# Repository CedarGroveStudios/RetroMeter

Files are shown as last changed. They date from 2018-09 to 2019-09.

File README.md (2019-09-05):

# RetroMeter
A breakout and FeatherWing PCB family with CircuitPython code that converts a +/-10V CV signal to a current level compatible with a retro analog ammeter. USB or 3 to 6V battery powered (no internal battery charger). From the collaborative project with John Park’s Workshop.

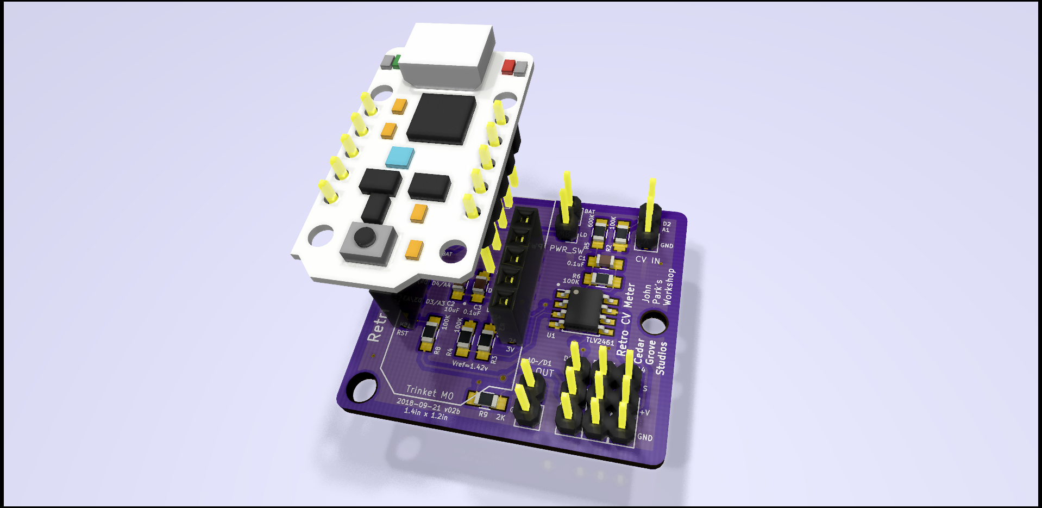
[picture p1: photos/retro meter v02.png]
Retro CV Meter and Trinket M0 Rendering


The Retro CV Meter breakout and FeatherWing board accepts a -10 to +10 volt signal and through an analog op-amp, translates it into a +3.3 to 0 volt signal connected to the Adafruit Trinket M0 or Feather's A1 analog input pin. The A0~ DAC output pin provides current output through a 2K-ohm resistor to the analog meter connection. The maximum DAC value (65535) produces 1.5mA to the attached meter.

The CircuitPython code reads the input voltage and adjusts the DAC output for the scale for the meter. The ``inertia_move`` helper integrates the incoming signal then sends the scaled and smoothed voltage to the on-board meter resistor to convert the voltage to current compabile with the analog meter. The integration routine protects the meter movement from sudden voltage changes.

The most recent version of the code reads a meter scale input from a potentiometer attached to pin A2. The D3 pin provides a PWM output proportional to the absolute value of the input voltage within the specified range.

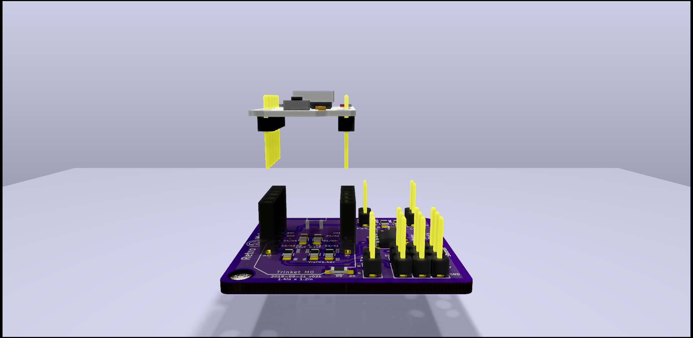
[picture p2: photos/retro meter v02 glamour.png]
Retro CV Meter and Trinket M0 Glamour Rendering


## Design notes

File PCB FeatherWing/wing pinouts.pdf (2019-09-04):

-EN | connect to GND to disable power also disables Feather MCU power
LED | glows when power is enabled
3V | 3.3 volt power from Feather MCU
GND | ground connection to/from Feather MCU

D5 | Digital output to LED buffer
D6 | Digital output to LED buffer
D9 | Digital output to LED buffer
A0 | DAC output to meter via R8 or R12
A2 | Analog input from input signal processing stage
A3 | Analog input from range selection potentiometer

D10 digital output to piezo speaker

LEDs:

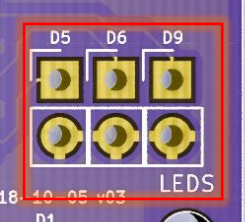
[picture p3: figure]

High-current buffered outputs for LEDs; 25mA max (connect anode to upper pin, cathode to lower pin) Recommended that LED current and brightness be controlled by PWM instead of adjusting R9-R11 values.

RANGE_SEL:
Range selection potentiometer connection (potentiometer wiper attached to S pin)

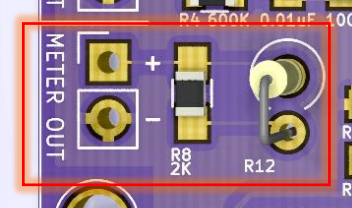
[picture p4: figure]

METER OUT:
Analog output to meter (note polarity)

R8 and R12:
Series resistance matched to meter full-scale current at +3.3volts

CV INPUT:
-10 volt to +10 volt control voltage input to signal processing stage

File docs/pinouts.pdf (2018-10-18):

PWR_SW:
Power switch pins in series with the positive battery input terminal

M OUT:
Analog output to meter (M = +, G = -)

R9:
Series resistance matched to meter full-scale current at +3.3volts

SenseBit Inputs/Outputs:
Unbuffered GPIO directly connected to the Trinket M0
(connect input/output signal to upper pin;
+3.3 volts power and ground available on the remaining two pins)

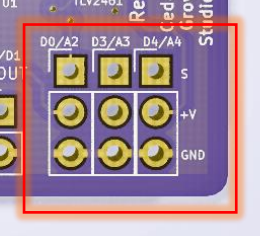
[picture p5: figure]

CV INPUT:
-10 volt to +10 volt control voltage input to signal processing stage

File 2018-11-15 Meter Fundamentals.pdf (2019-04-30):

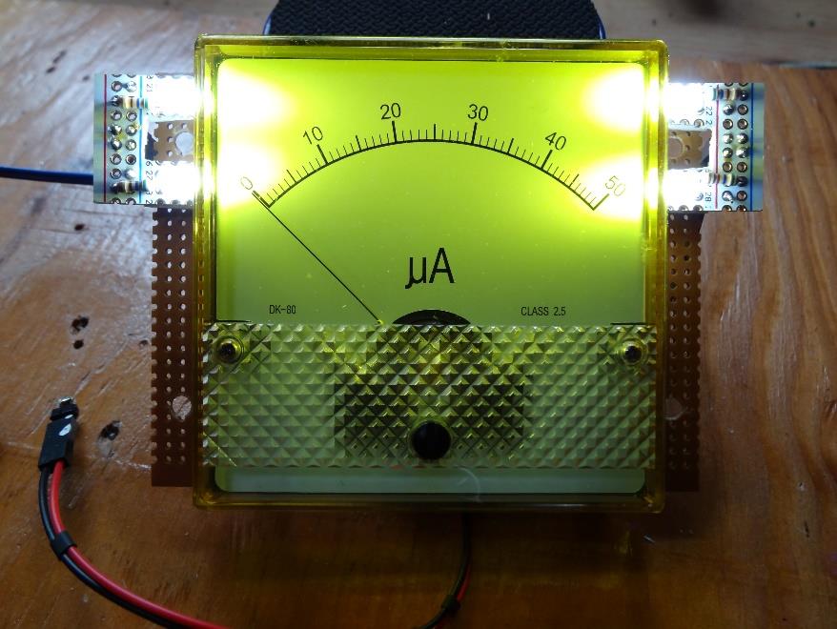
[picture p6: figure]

Meter Fundamentals.docx | 1

# Analog Meter Fundamentals

Jan Goolsbey, Cedar Grove Studios
November 2018

## 1. Analog Meter Fundamentals

Analog meters have a wonderful retro look and are easy to read with a glance. Can you make one work with your project? With one of these meters, you’ll be able to display either voltage or current of almost any range or value with some simple components. Ohm’s Law will become your analog friend.

### 1.1 Overview

Analog meters used to be an excellent and sometimes the
only way to display electronic circuit activity. They are round,
square, rectangular, lighted, mirrored, small and large, slow and fast. They have been used to measure voltage, current, power, resistance, radio frequency (RF) fields, engine RPMs, audio volume units (VU), and just about anything else. The meter’s lightweight needle darts above a printed scale,
eventually settling to point at the measured value.

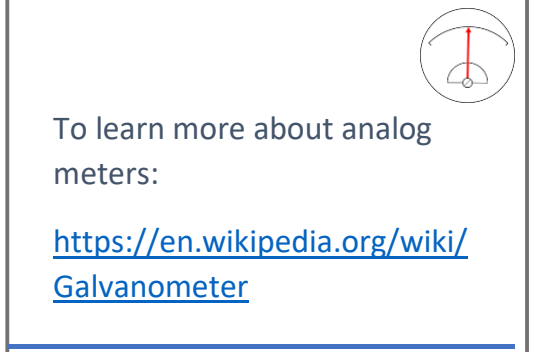
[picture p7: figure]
To learn more about analog meters:; https://en.wikipedia.org/wiki/ Galvanometer

Analog meters are closely related to galvanometers and motors. Common analog meters are built with magnets, a small coil of wire, jewel pivot bearings, fragile pointers, and a miniature spring (like the balance wheel hairspring in a mechanical timepiece), all sealed in a wind-tight case with a clear cover. With the proper components attached, these meters can measure signal levels as sensitive as millivolts and microamperes all the way to kilovolts and tens of
Amperes. Changing the displayed scale is as easy as printing
and attaching a new scale legend.

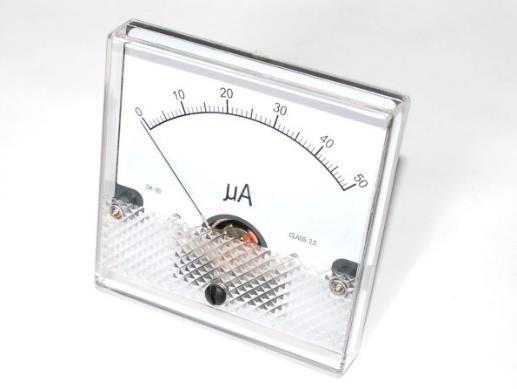
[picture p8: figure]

Although not widely in use as of this writing, analog meters are still available to purchase. Many meters can be reclaimed from old equipment and repurposed. An analog meter can add retro elegance to a modern project. Would one work with yours?

For the examples in this guide, we’ll be using a 50-
microampere analog panel meter from Adafruit (PID # 252). (https://www.adafruit.com/product/252)

### 1.2 Meter Electromechanics

Common analog meters consist of a moving wire coil suspended in a magnetic field created by a stationary core and surrounding permanent magnets. The coil is suspended on jeweled bearings with tension provided by one or two spiral wound springs that return the coil to a resting position when no current is applied. As current is applied to the coil, it deflects the attached indicator needle linearly in proportion to the amount of current flowing through the coil.

When no current is flowing through the meter, the indicator needle will rest at the zero point, usually on the left of the scale, sometimes in the center. If connected correctly, the needle will deflect towards the full-scale position in proportion to the current flowing through the meter. If the connection is reversed, the needle will move to a value less than the resting (zero) position. Reverse deflection below the limit of the scale can damage the sensitive and fragile coil assembly and should be avoided. Similarly, if too much current is applied, the coil will move beyond the full-scale value and cause similar damage to the

Adafruit’s Analog Panel Meter coil assembly. The slang phrase for pushing a meter beyond its physical limits until the needle hits a mechanical stop is called “pegging the meter.”

Moving-coil meters respond to direct-current (DC) flow. Most commercially available meters respond to current levels as low as 25 microamperes and up to 10 milliamperes full-scale. With some simple external components and Ohm’s Law, analog meters can be employed to display kilovolts and deca-amperes.

Using a meter for displaying a current level is simple: connect it in series between a power source and a load then read the value on the scale. The meter’s needle will point to a value as accurate as the meter can measure in its range, usually within 1% to 5% of the full-scale value. A resistor added across the meter’s terminals can be used to extend the current measurement range of the meter.

If it’s voltage that you want to measure with the analog meter, select and place a resistor in series with one of the meter’s terminals. The voltage range can be adjusted to a wide range by modifying the value of the series resistor.

We’ll need to know a couple of things about the meter to proceed, its full-scale current value (likely printed on the meter or accompanying documentation) and the voltage drop measured across the meter when the needle is deflected to full-scale. If you don’t know your meter’s full-scale current value or voltage drop, then briefly skip to section 3. Characterize the Meter to discover those values. You will need both in order to adapt the meter to measure a variety of full-scale voltage and current levels.

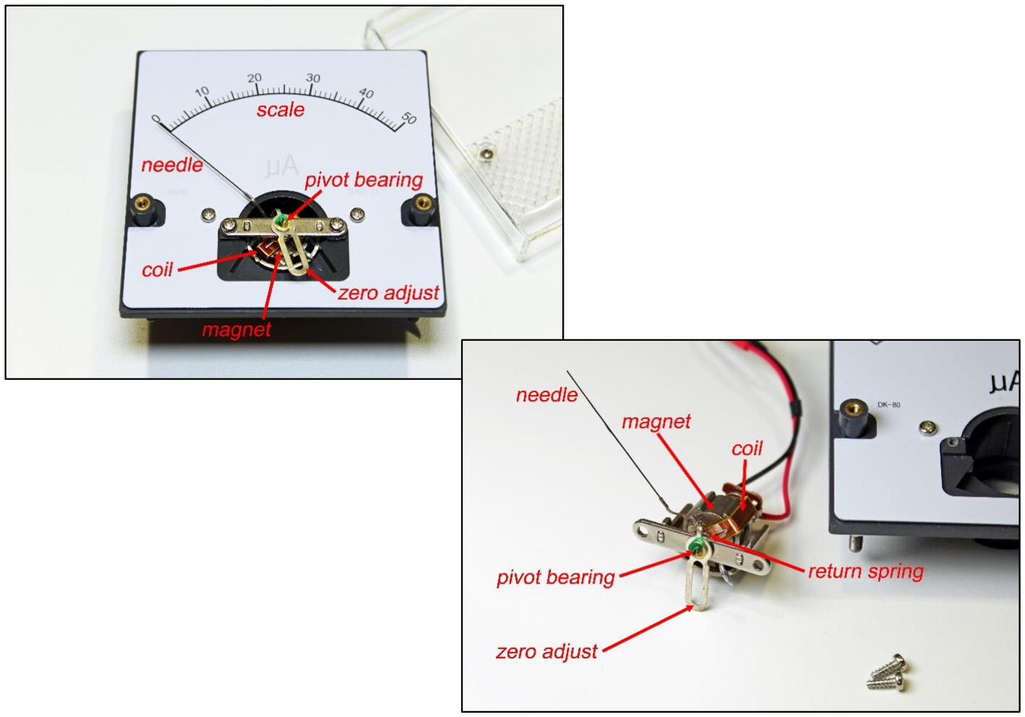
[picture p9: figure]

### 1.3 Measure Current

Measuring current is natural for most moving-coil analog meters. The meter’s primary mode of operation is to measure the amount of current passing
through its coil. To use a meter to measure the current flow of a circuit, select a meter with a full-scale value that is greater than the maximum current expected. Place the meter in series with the
power source and the circuit
under test (the “load”) to

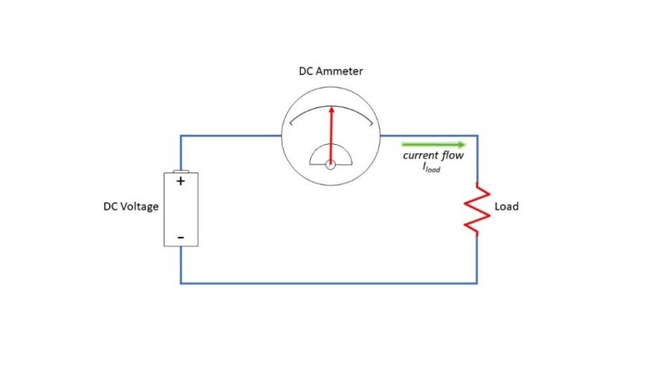
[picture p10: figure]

measure the amount of current the circuit is drawing from the power source.

Most meters are very sensitive and can only measure a small amount of current at full-scale. For example, our 50-microampere (uA) meter is too sensitive to measure the current through a typical light-emitting-diode (LED) since an LED will draw 5 to 20 milliamperes (mA). That’s at least 100 times the current the meter can handle and will certainly damage the meter! (Remember what happens when the needle goes past full-scale?) If you’re planning to measure higher values of current than the meter’s rated range, we’ll need to make a couple of calculations using Ohm’s Law.

1.3.1 More Current (Introducing the Shunt Resistor)
A resistor placed in parallel with the meter can be used to pass most of the circuit’s current around the meter while still allowing a smaller amount of current -- proportional to the total current – to pass through the meter. In effect, the parallel resistor shunts current that could damage the meter directly into the load. Here’s how it works.

The entire current to the load
passes through both the meter
and the shunt resistor. Because of differences between the meter’s internal resistance (Rmeter) and that of the shunt resistor (Rshunt), the meter will see a just fraction of the total current. That fraction is directly proportional to the ratio of the
meter and shunt resistance
values. If the load requires 50mA

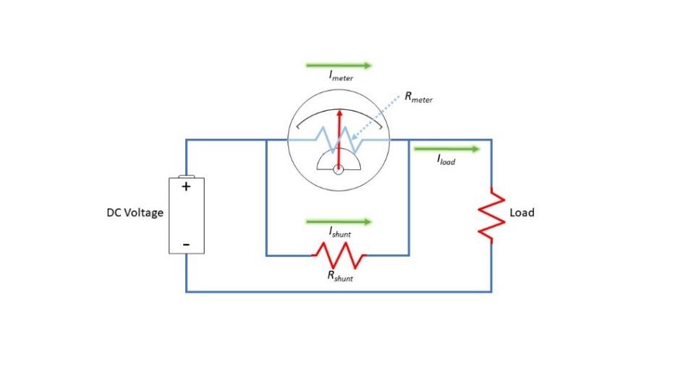
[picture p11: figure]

and if the meter can only indicate a maximum of 50uA (0.05mA), the shunt resistor will need to divert 49.95mA away from the meter.

Since the voltage across the shunt resistor is the same as the meter voltage, it’s easy to calculate the value of the shunt resistor. Here’s the formula:

Rsℎunt =

Vmeter

Iload − Imeter

=

Vmeter

Isℎunt

Substitute these values and solve:

Rsℎunt =

0.0922V
0.050A − 0.00005A = 1.85 oℎms

To bypass the current not used by the meter, our shunt resistor will need to have a value of 1.85 ohms.

We’ll need one more calculation to determine how much heat the shunt resistor will need to dissipate when the circuit draws the maximum of 50mA. For many electronic devices, heat dissipation is measured in Watts. Resistors with a higher wattage value can safely dissipate more heat than those of a low wattage. Shunt resistor heat dissipation is a very important number to know when measuring current; if exceeded, damage may occur.

The formula for determining wattage is:

Wsℎunt = Vmeter ∗ Isℎunt

Wsℎunt = 0.0922V ∗ 0.04995A = 0.0046W

Substituting the voltage across the shunt resistor (0.0922V) and its current (0.04995A) tells us that the shunt resistor will need to be sized to dissipate 4.6mW, well below a typical resistor’s 128mW (1/8W) maximum dissipation value.

DigiKey stocks a 1.82-ohm resistor with a resistance value close enough to work in this example given the +/-3% accuracy of the 50uA meter. This resistor’s specified 250mW dissipation value is more than adequate, as well.

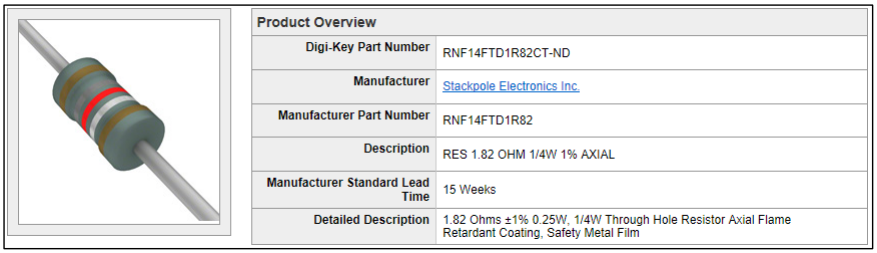
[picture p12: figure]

In summary, measuring current greater than the meter’s full-scale value is just a simple matter of understanding the maximum load current to be measured, the meter’s full-scale current value, and the

Vmeter = 92.2mV = 0.0922V

Iload = 50mA = 0.050A

Imeter = 50uA = 0.00005A meter voltage when the needle is at full-scale. Throw Ohm’s Law and a power formula into the mix and you can adjust the meter to measure almost any DC current value.

The printed scale may not match the new full-scale value. If that’s the case, look at the section, 2. Print a New Scale.

Now that we can measure various current values using an analog meter, it’s time to move on to measuring voltage.

### 1.4 Measure Voltage

A sensitive analog ammeter is capable of measuring voltage with the addition of a single series resistor. The resistor is used to limit the current traveling to the meter so that the meter can proportionally respond to the measured voltage
value.

In this diagram, we’re measuring
the voltage across a load that’s supplied by a battery. The battery’s DC voltage provides a current through the series resistor (Rseries) and the meter that is in proportion to the resistance of Rseries. For example,
let’s assume that we’re using our
friendly Adafruit 50uA meter and

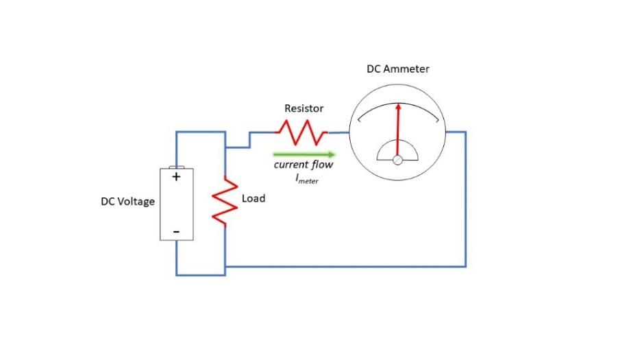
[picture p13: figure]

the battery is supposed to provide at least 12 volts. Let’s calculate the value of Rseries that will result in full-scale needle deflection if the voltage reaches 50 volts.

Rseries =

Vfullscale − Vmeter

Imeter

Substitute these values and solve:

Rseries =

50V − 0.0922V
0.000050A

= 998.16K oℎms

The closest value in DigiKey’s stock is 1M ohms. That value will introduce an error of only 0.2%, well within the meter’s accuracy.

Vfullscale = 50V

Imeter = 50uA = 0.000050A

Vmeter = 92.2mV = 0.0922V

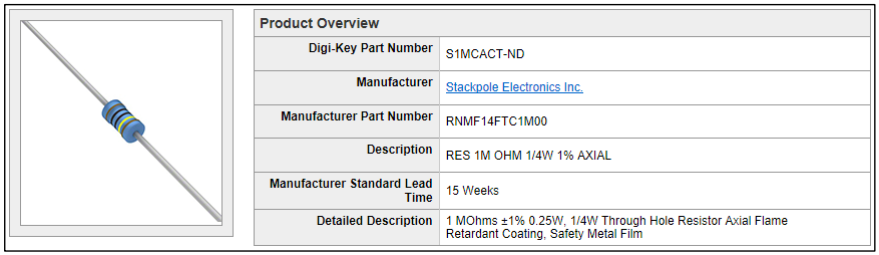
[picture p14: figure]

Let’s try one more example. We would like the full-scale voltage value to be 3.3 volts, the maximum voltage used by many microcontrollers.

Rseries =

Vfullscale − Vmeter

Imeter

Rseries =

3.3V − 0.0922V
0.000050A

= 64,156 oℎms

We’ll select a resistor as close to that as possible. DigiKey stocks resistors with values of 63.4K and 64.9K ohms. We’ll pick the closest one, 64.9K ohms. The error introduced by the resistor selection is just 1.2%, sufficient for most projects.

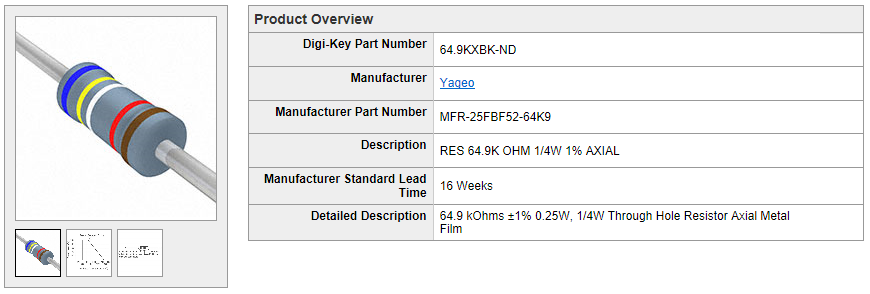
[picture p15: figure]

Okay, but the meter’s scale is shown as 0 to 50uA. The printed scale does not match the new full-scale value of 3.3 volts. The next section, 2. Print a New Scale, will help with that.

## 2. Print a New Scale

So, the 0 to 50 uA meter scale doesn’t represent the values you plan to measure? A new label can be made from a sheet of paper and a protractor. It can be drawn by hand or using your favorite software drawing, CAD, or photo tool. The process is pretty much the same regardless of the media or tool.

Most analog meter scales can be matched to a degree spread on a protractor. In the case of the Adafruit 50uA meter, the needle travels along 90 degrees of a circular arc with a radius of 4cm. Laying that out using a protractor or on an image of a protractor is the first step. After that, you can add the graduations and the legend as required. If the scale you need is linear, that’s easy. A logarithmic scale will probably take longer and will require some planning and patience. If you’re making a weather gauge, then you may only need three colorful symbols (stickers?) for sunny, cloudy, and precipitation such as an image of the warm sun, a menacing cloud, and when it’s raining cats and dogs. Use your imagination!

Once designed, print a draft version to make certain it will fit. For most meters, cut the paper scale to a rectangle the size of the visible window. After removing the meter’s clear cover, place the new scale over the old scale and under the needle. Try not to bump the needle or meter movement – it’s easy to throw the sensitive parts out of alignment. If the draft scale fits correctly, print the final scale on photographic paper, otherwise continue to work the dimensions until the draft scale fits. Secure the new scale with two or three dots of glue from a glue stick or use three pieces of clear tape along the top and sides. If you use tape, keep the overlap on the face of the scale as small as possible so the tape won’t be visible.

Free-use protractor images and design files can be found on many Internet sites. One of my favorites is Michael Ossmann’s excellent quality Print a Protractor site (http://www.ossmann.com/protractor/). The files are available for use under a Creative Commons Attribution 2.5 License.

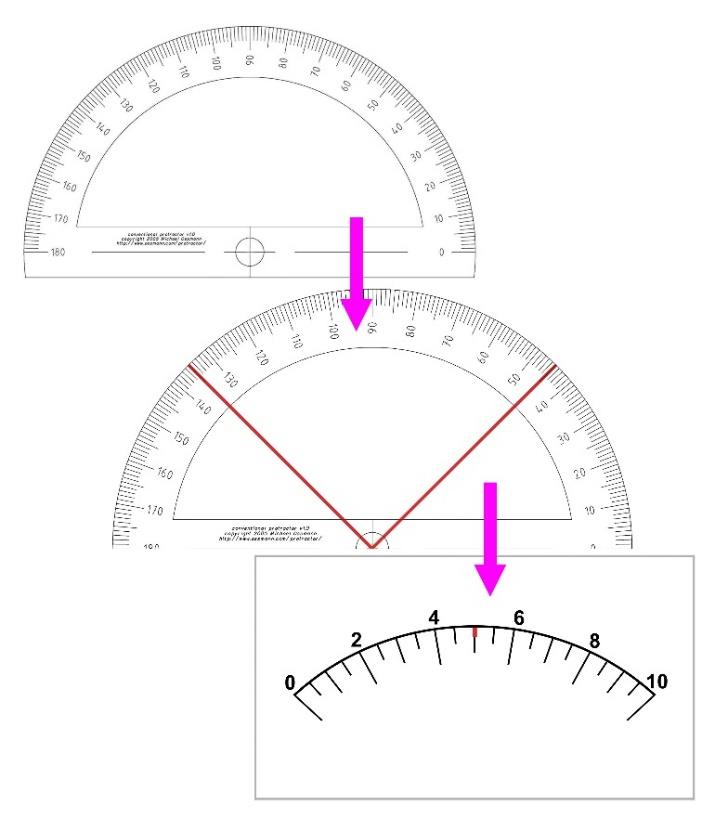
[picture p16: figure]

## 3. Characterize the Meter

### 3.1 Find the Meter’s Numbers

If you are repurposing a used meter, it’s likely that the full-scale current range isn’t known. We’ll walk through the process to determine a meter’s range using a stable power source, a few resistors, two potentiometers, and a digital volt meter – providing that the meter movement wasn’t previously damaged, of course.

First, carefully open the case of the meter to confirm that the meter is indeed a moving coil meter (capable of responding to DC current). If you see a fixed coil, it may respond only to voltage or AC current and won’t be useful for anything else than that.

Next, look to see if resistors, copper bars, or other components are attached to the wires coming from the meter coil. If so, carefully remove the components and connect the coil wires to the meter terminals, being extra careful not to disturb the meter movement or needle. Close the meter case when finished removing components. The meter should now respond to a DC current input.

Since most meters will have a manufacturer’s name and model number, search the Internet for information about the meter. The range of the meter and voltage drop may be easy to find from a reliable source like the manufacturer or a commercial supplier. If so, you’re done and can skip the rest of this sub-section. If it looks dubious or you can’t find anything that’s helpful, then you’ll have to measure those values yourself.

The majority of common DC Ammeters have full-scale ranges from 30uA to 10mA. To measure a meter’s range, all we’ll need is a reliable way of generating a measurable current. That’s where the power source and resistors will be
needed.

To keep from damaging the
meter by applying too much current, we’ll start by
applying a current level up to 330uA using a 3.3V-volt
power source. Ohm’s Law
tells us that to create 330uA of current using a 3.3-volt power source we’ll need a
10,000-ohm (10K-ohm)
resistor.

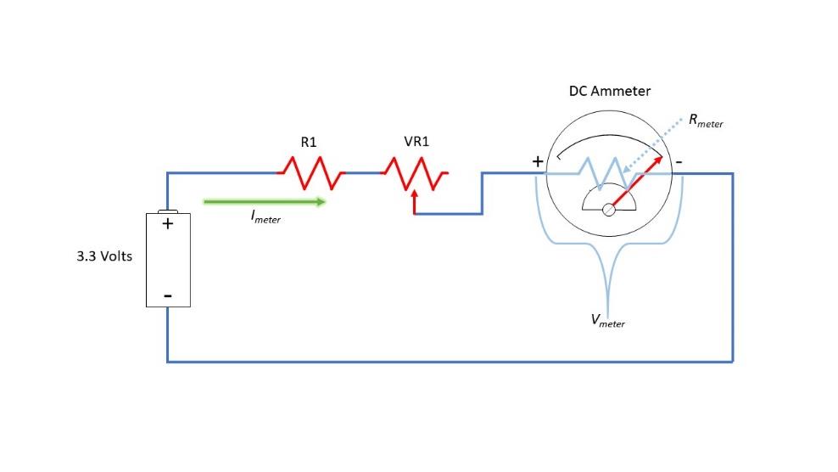
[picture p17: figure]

R1 =

3.3V
0.00033A

= 10,000 oℎms

By adding a 100K-ohm potentiometer in series with the 10K-ohm resistor, the circuit will supply a variable current from 30uA to 330uA depending on the position of the potentiometer. When the potentiometer’s resistance is the lowest, the current to the meter will be at the high value, 330uA. When the resistance is highest, the current will be at the lower value of 30uA.

Begin the test with the potentiometer at its highest resistance value, then attach the meter to the circuit. Note the needle deflection, if any. It the needle deflects below zero, then reverse the meter connections and try again. Slowly decrease the potentiometer’s resistance until the needle deflects to full-scale. If it doesn’t reach full-scale, then it’s time to change the resistor and potentiometer to values that can provide more current.

Test Current Range | Value of R1 | Value of VR1
30uA to 330uA | 10K ohms | 100K ohms
300uA to 3.3mA | 1K ohms | 10K ohms
327uA to 33.0mA | 100 ohms | 10K ohms

Using the table, start with the resistor combination for the lowest test current range first then work your way up to the highest until the potentiometer can be adjusted to give a full-scale reading. If you still don’t have a needle deflection after using the resistors for the highest range, then there may be a problem with the meter such as an open circuit, damaged coil, or mechanical obstruction.

When the needle reaches full-scale, measure the voltage across the meter terminals using the digital voltmeter set to DC volts. This is the meter voltage drop value. Write it down for future use.

Disconnect the meter and remove the power source. Set the digital voltmeter to resistance mode and measure the total resistance of the fixed resistor plus that of the potentiometer at its current setting (R1 + VR1). Time for the calculator and Ohm’s Law.

The full-scale value of the meter is calculated from the applied voltage (3.3V) and the series resistance value just measured.

Imeter =

3.3V − Vmeter
R1 + VR1

Write down the full-scale meter current value. Matter of fact, you may want to scribe it and the meter voltage drop value on the back of the meter case to keep the numbers handy.

### 3.2 An Example

Let’s set up the circuit with a 3.3-volt power
source to measure the full-scale range and
meter voltage drop of our Adafruit 50uA meter. We’ll start with the lowest test current range resistor and potentiometer, 10K-ohms and 100K-ohms. Following the procedure, the potentiometer is adjusted to the full-scale value. For this example, we’ll pretend we don’t know that it’s indicating 50uA.

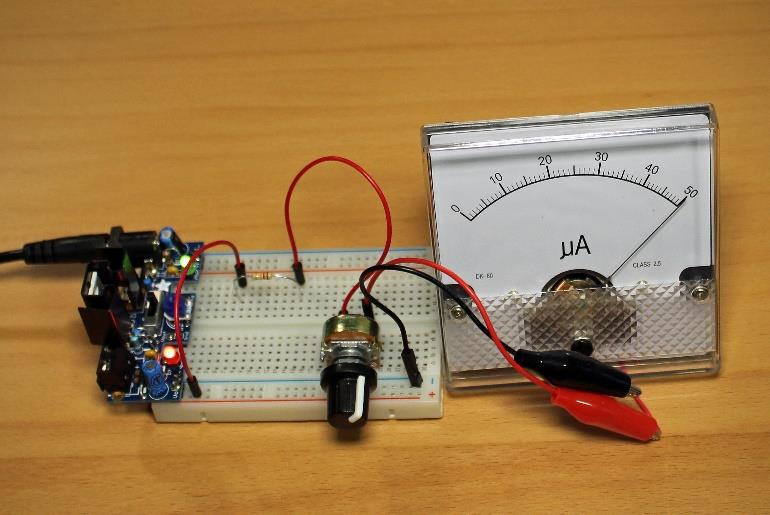
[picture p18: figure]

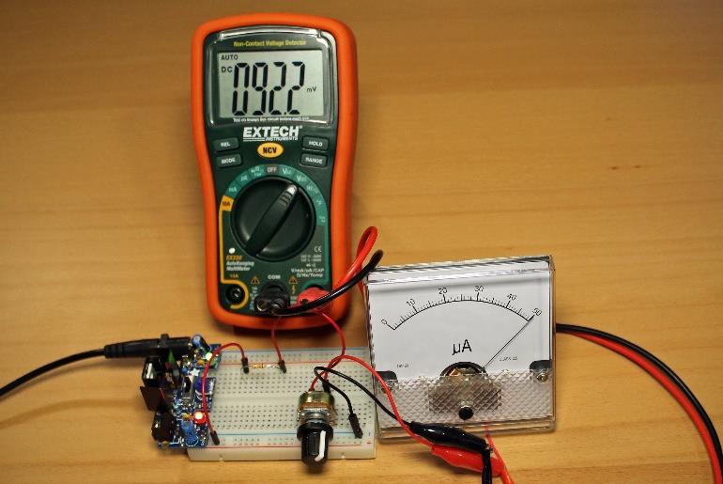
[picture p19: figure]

While the meter is still pointing to full-scale, we’ll attach our digital multimeter to the meter terminals to read the DC voltage drop across the meter. Our multimeter reads 92.2 millivolts (mV). Write that down; we’ll need it soon.

Without changing the potentiometer, disconnect the meter and the power source. We will need to measure the total resistance of R1 and VR1 next. Set the multimeter to resistance measuring mode and place the first probe on the end of the resistor that was connected to the power source. Attach the second probe to the potentiometer pin that was previously connected to the meter.

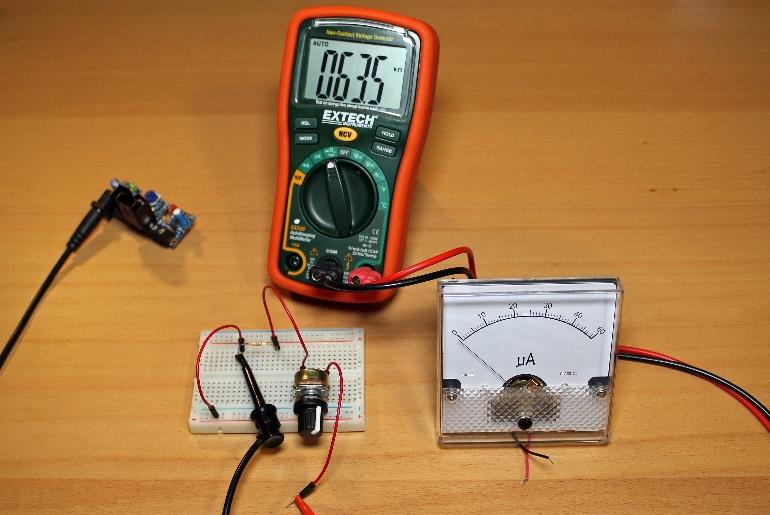
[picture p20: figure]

The multimeter is telling us that the combined resistance that produces a full-scale deflection with a 3.3-volt power source is 63.5K ohms. Make a note of that value and get ready for a quick Ohm’s Law calculation of the meter’s full-scale value.

Imeter =

Vsource − Vmeter
R1 + VR1

=

3.3V − 0.0922V
63,500 oℎms

= 50.52uA

After the test, we can reliably say that this meter is a 50uA full-scale DC ammeter. We now know the important numbers for our Adafruit meter: It has a full-scale value of 50uA and a meter voltage drop of 92.2mV. Keep track of these numbers for each analog meter in your inventory.

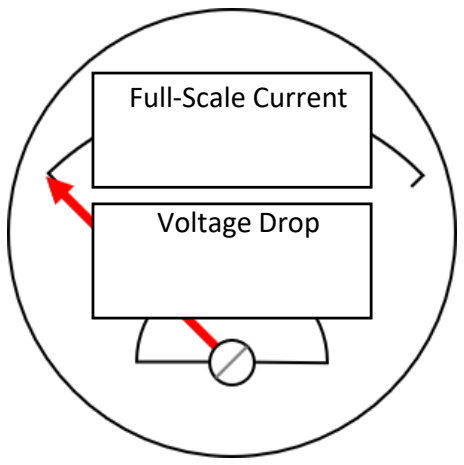
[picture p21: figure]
Full-Scale Current; Voltage Drop

### 3.3 Understanding the Meter Voltage Drop

Inside the meter is a coil of wire that builds up its own magnetic field causing the needle to deflect. The copper wire used for the coil isn’t a perfect conductor, so the coil will have some resistance. The more sensitive the meter, the higher the coil resistance. Sensitive meters need more turns of wire in the coil to disrupt the field from the
permanent magnets in order to
be strong enough to move the
needle.

According to Ohm’s Law,
whenever current flows through resistance, a directly
proportional voltage develops across that resistance. The voltage that is created when
passing current through the
meter at full-scale is called the

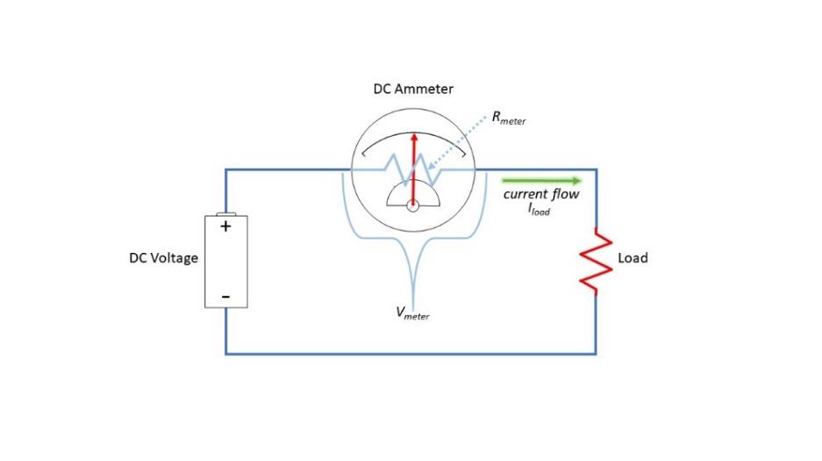
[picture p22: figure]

meter’s voltage drop (Vmeter). Knowing the meter voltage drop will very important as we put external circuity on the meter to increase the meter’s current measuring range or to measure voltage instead of current.

For example, a 3.3 voltage source with the 10K resistor plus the 100K-ohm potentiometer used in subsection 3.1 Find the Meter’s Numbers will provide 50uA through the meter when the total of the resistor plus the potentiometer’s resistance is approximately 66K ohms. The voltage across the terminals of the Adafruit 50uA meter measures about 92.2mV when the meter is pointing to 50uA on the scale.

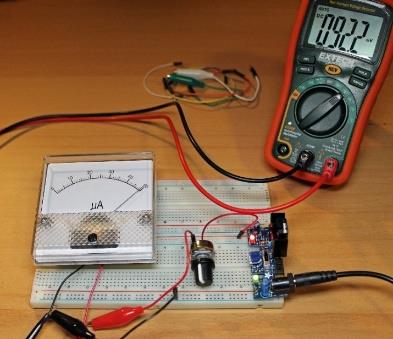
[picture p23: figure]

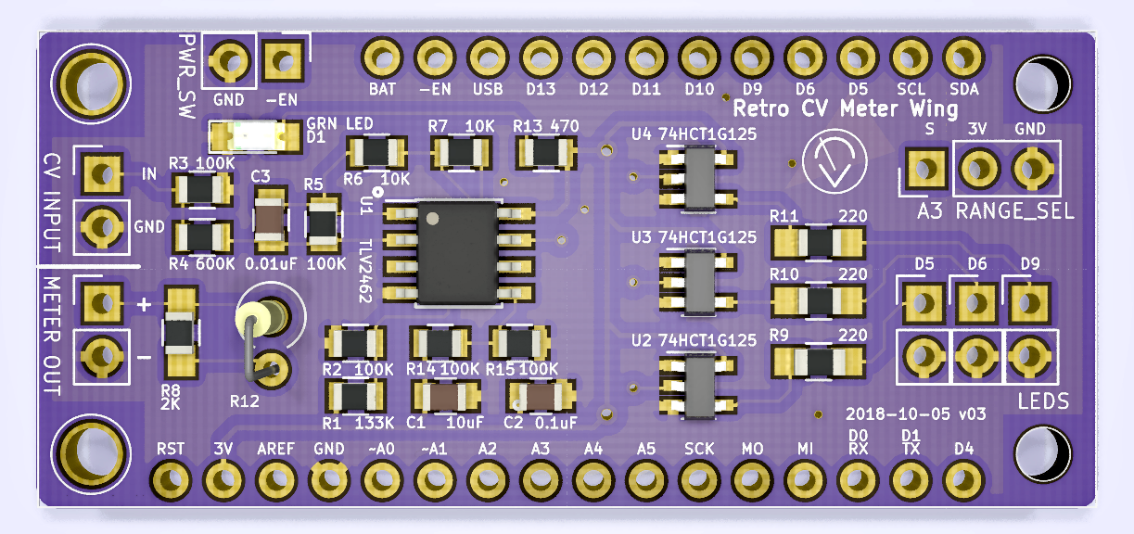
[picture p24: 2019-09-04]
photos/retro meter v03 pinout top.png

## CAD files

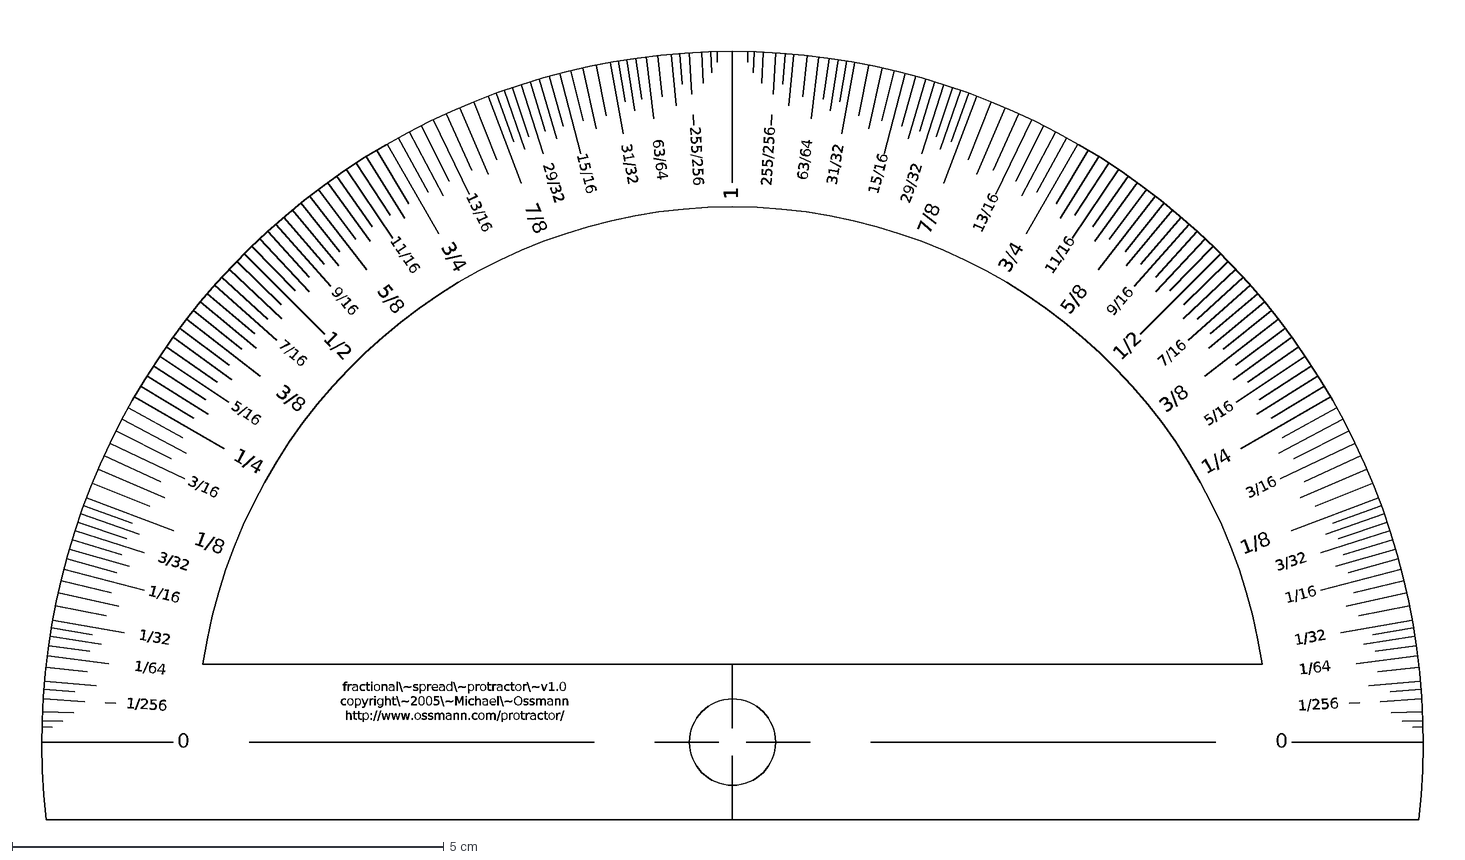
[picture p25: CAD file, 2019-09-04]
docs/2018-09-05 meter tutorial/photos and drawings/fractional-spread-protractor.dxf
1/2
1/4
3/4
1/8
3/8
5/8
7/8
1/16
3/16
5/16
7/16
9/16
11/16
13/16
15/16
1/32
3/32
31/32
29/32
1/64
63/64
1/256
1
0
255/256
fractional\~spread\~protractor\~v1.0 copyright\~2005\~Michael\~Ossmann http://www.ossmann.com/protractor/

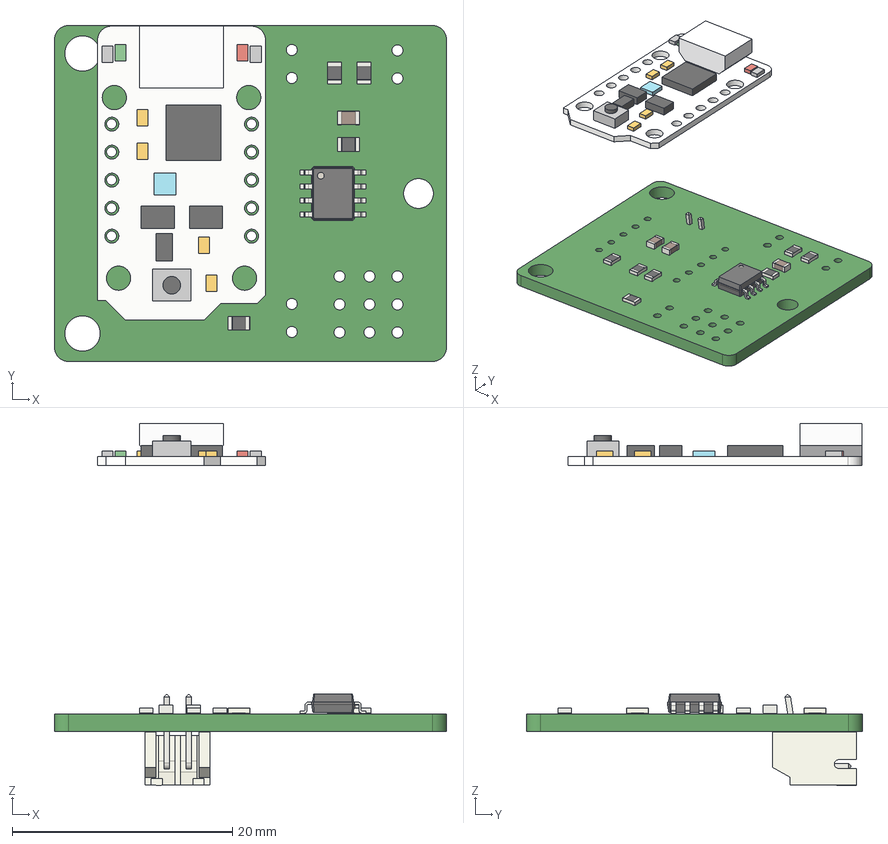
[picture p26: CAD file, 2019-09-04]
docs/retro meter v02.stp
35.6 x 30.5 x 32.9 mm
Pin_Header_Straight_1x05_Pitch2.54mm x 2
Socket_Strip_Straight_1x05_Pitch2.54mm x 2
Pin_Header_Straight_1x02_Pitch2.54mm x 3
Pin_Header_Straight_1x03_Pitch2.54mm x 3

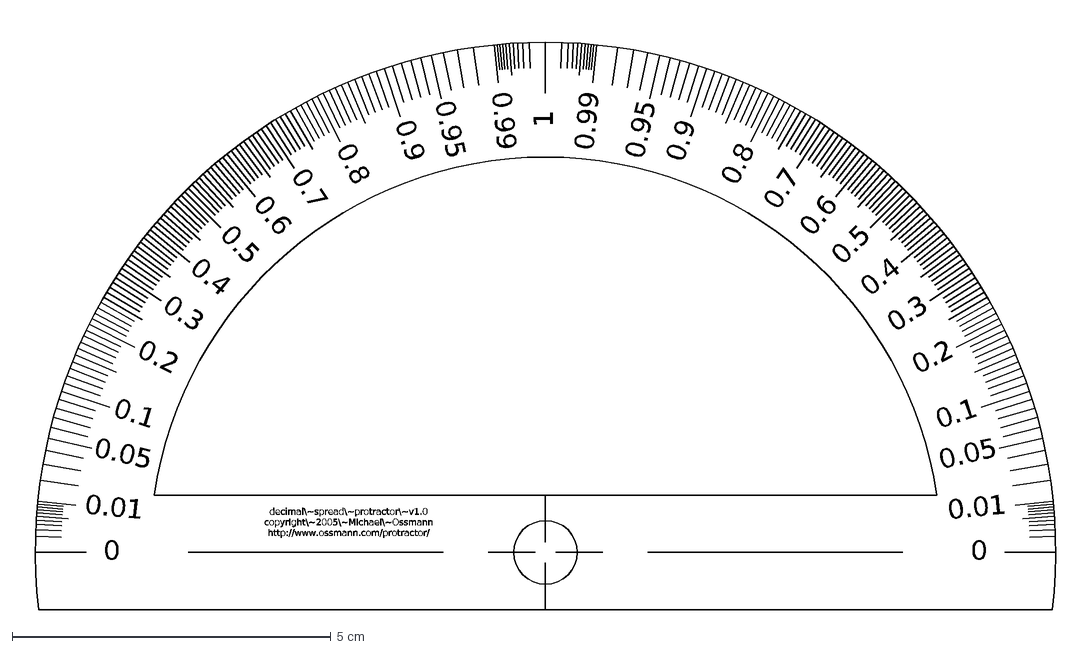
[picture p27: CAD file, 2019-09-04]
docs/2018-09-05 meter tutorial/photos and drawings/decimal-spread-protractor.dxf
0.1
0.05
0.01
0.2
0.3
0.4
0.5
0.6
0.7
0.8
0.9
0.95
0.99
1
0
decimal\~spread\~protractor\~v1.0 copyright\~2005\~Michael\~Ossmann http://www.ossmann.com/protractor/

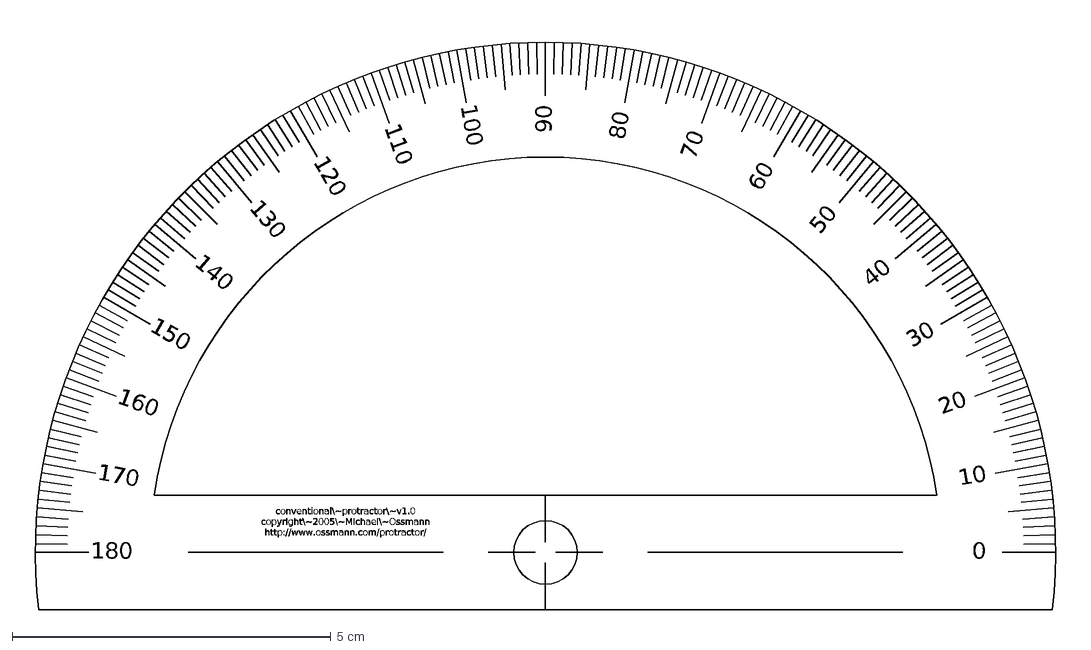
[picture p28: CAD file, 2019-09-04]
docs/2018-09-05 meter tutorial/photos and drawings/conventional-protractor.dxf
0
10
20
30
40
50
60
70
80
90
100
110
120
130
140
150
160
170
180
conventional\~protractor\~v1.0 copyright\~2005\~Michael\~Ossmann http://www.ossmann.com/protractor/

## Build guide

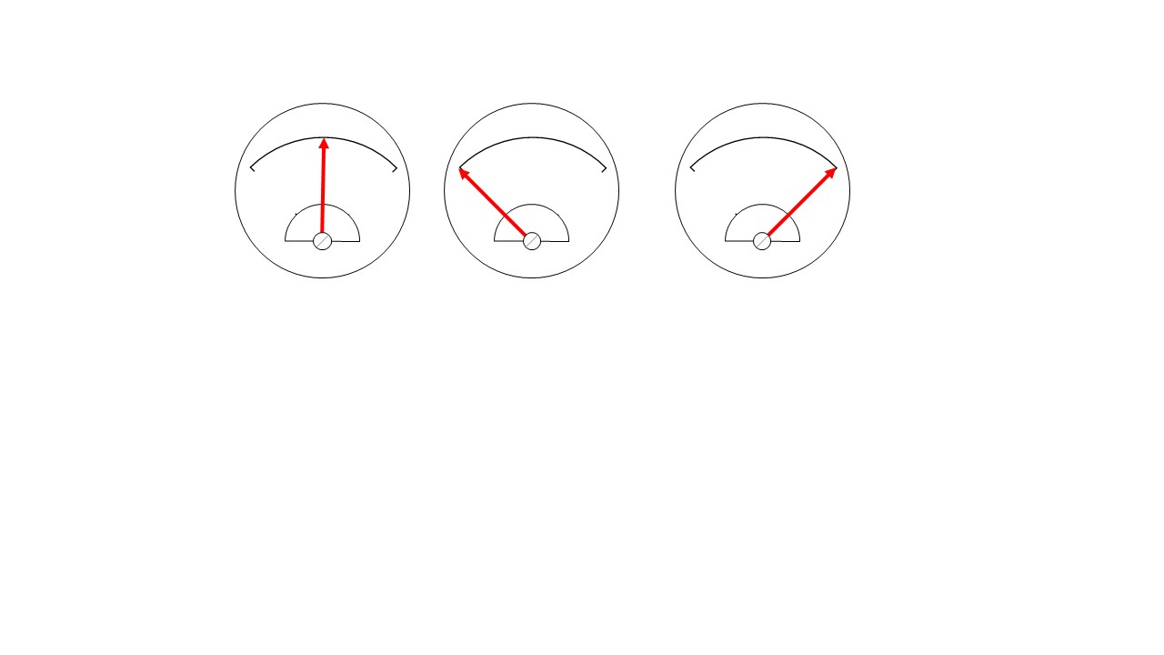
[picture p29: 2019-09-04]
docs/2018-09-05 meter tutorial/photos and drawings/meter graphics all v3/Slide15.JPG

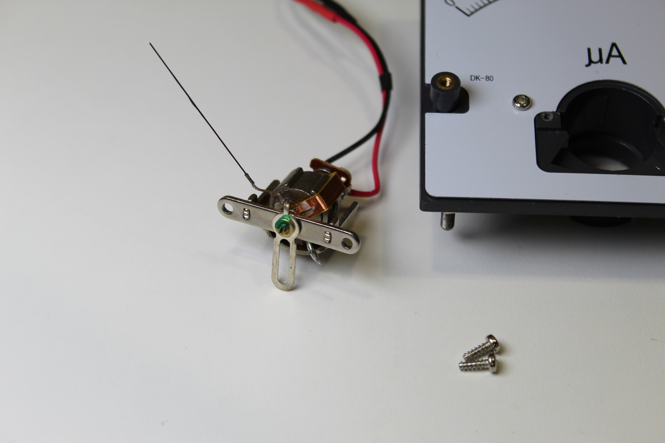
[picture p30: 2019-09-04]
docs/2018-09-05 meter tutorial/photos and drawings/IMG_0374.JPG

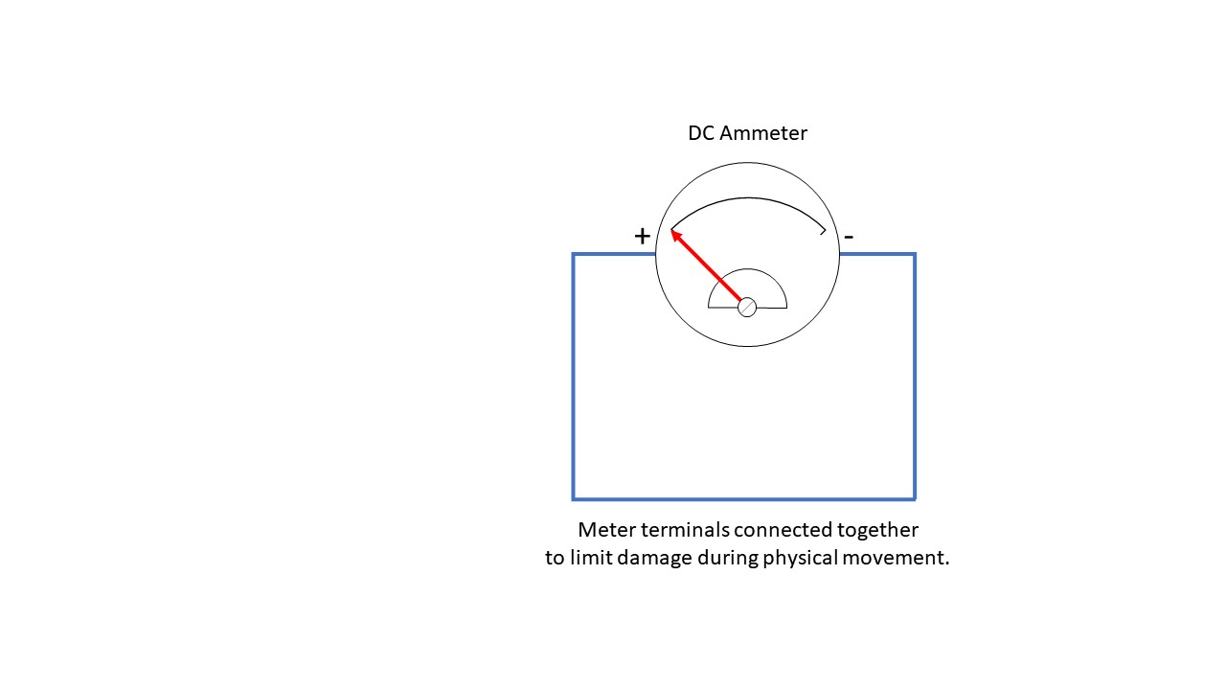
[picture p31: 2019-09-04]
docs/2018-09-05 meter tutorial/photos and drawings/meter graphics all v3/Slide7.JPG

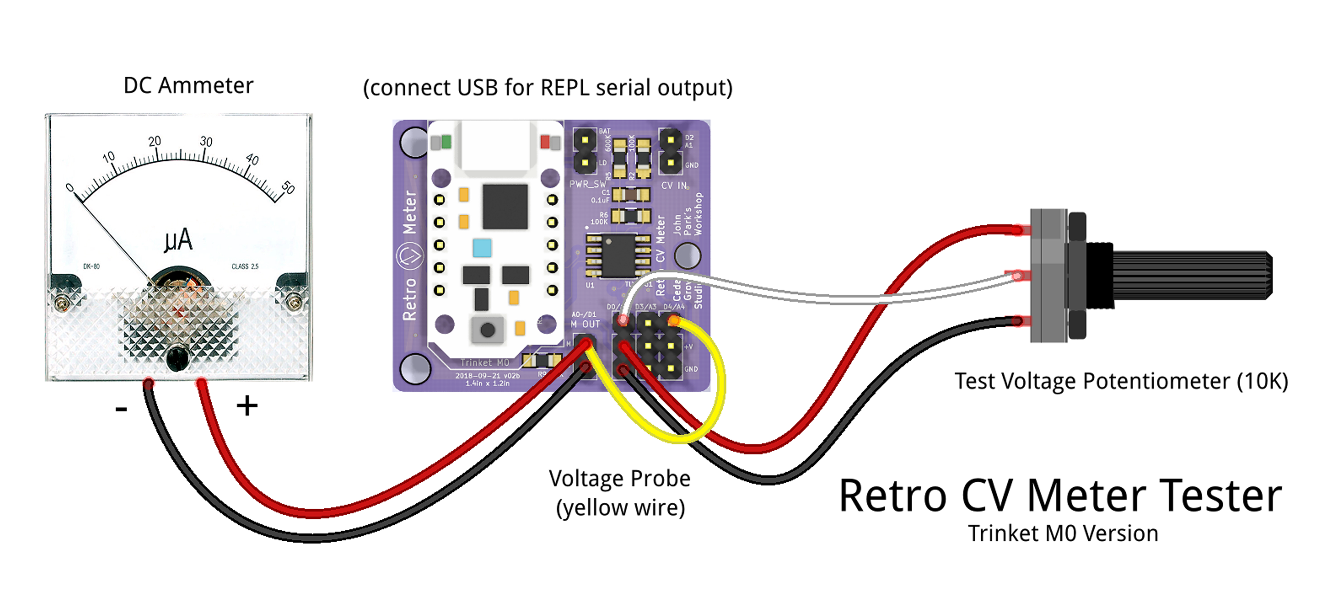
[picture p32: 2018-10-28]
docs/Meter Tester Wiring Trinket.png

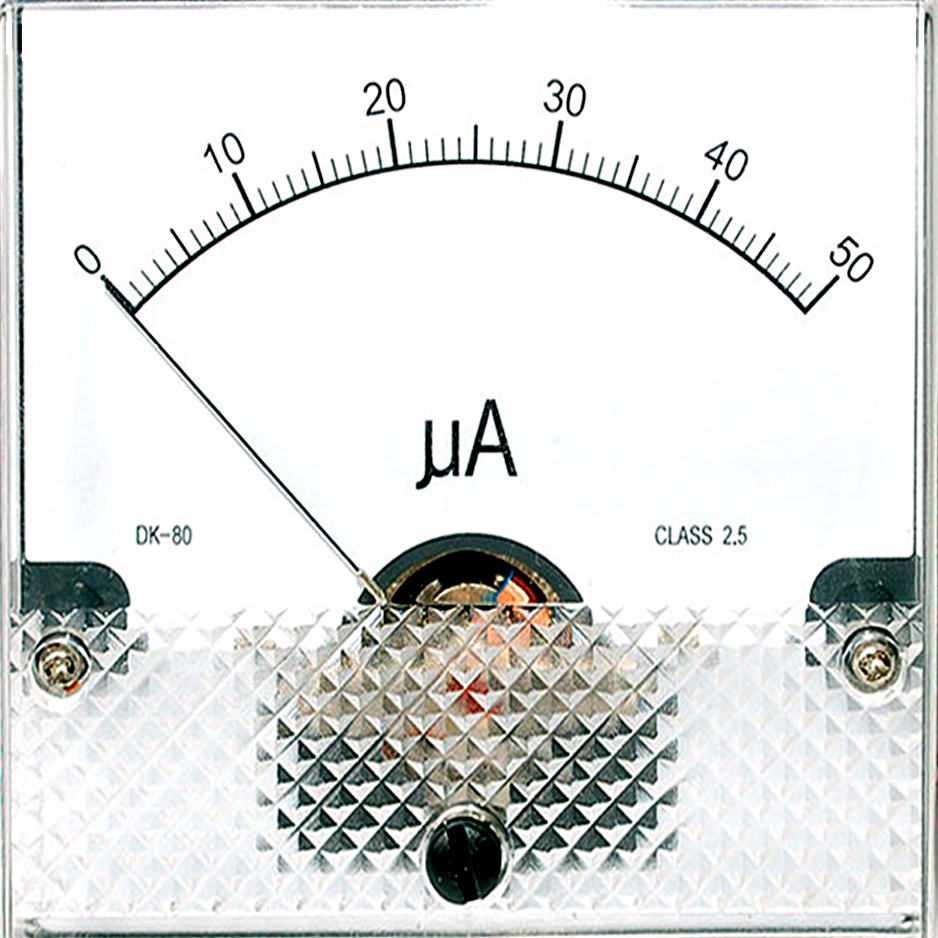
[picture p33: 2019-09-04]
docs/2018-09-05 meter tutorial/photos and drawings/Analog Panel Meter 252-02a.jpg

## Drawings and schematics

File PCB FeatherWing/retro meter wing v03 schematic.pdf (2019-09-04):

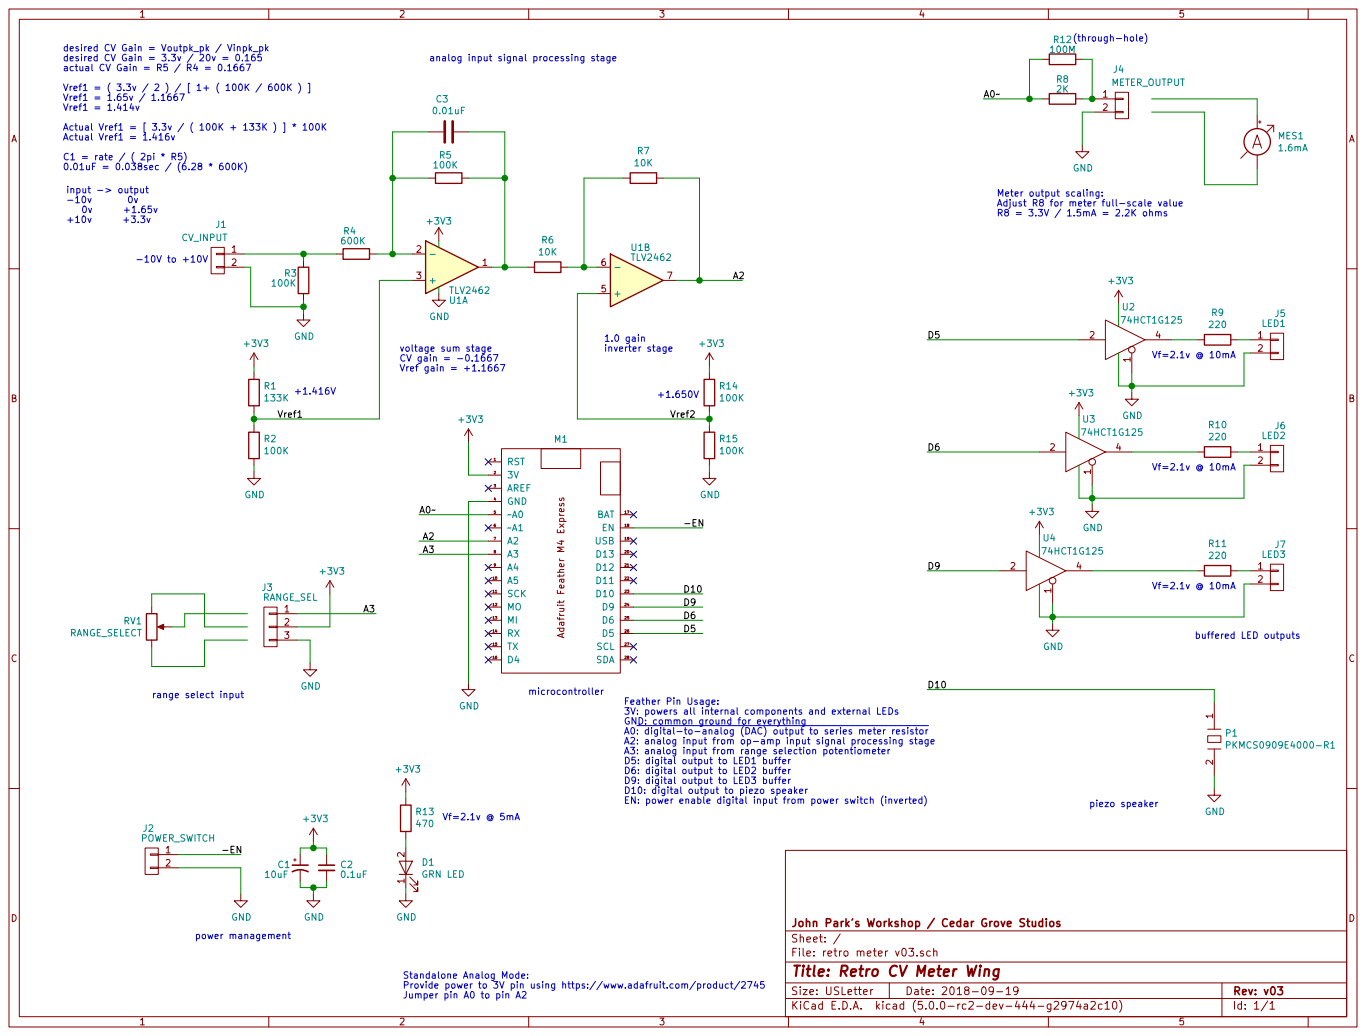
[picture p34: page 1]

desired CV Gain = Voutpk_pk / Vinpk_pk desired CV Gain = 3.3v / 20v = 0.165
actual CV Gain = R5 / R4 = 0.1667 Vref1 = ( 3.3v / 2 ) / [ 1+ ( 100K / 600K ) ] Vref1 = 1.65v / 1.1667 Vref1 = 1.414v Actual Vref1 = [ 3.3v / ( 100K + 133K ) ] * 100K

Adjust R8 for meter full-scale value R8 = 3.3V / 1.5mA = 2.2K ohms R8

Feather Pin Usage:
3V: powers all internal components and external LEDs
GND: common ground for everything
A0: digital-to-analog (DAC) output to series meter resistor
A2: analog input from op-amp input signal processing stage
A3: analog input from range selection potentiometer
D5: digital output to LED1 buffer
D6: digital output to LED2 buffer
D9: digital output to LED3 buffer
D10: digital output to piezo speaker
EN: power enable digital input from power switch (inverted)

File: retro meter v03.sch Sheet: / John Park's Workshop / Cedar Grove Studios

Id: 1/1 Title: Retro CV Meter Wing

Provide power to 3V pin using https://www.adafruit.com/product/2745
Jumper pin A0 to pin A2

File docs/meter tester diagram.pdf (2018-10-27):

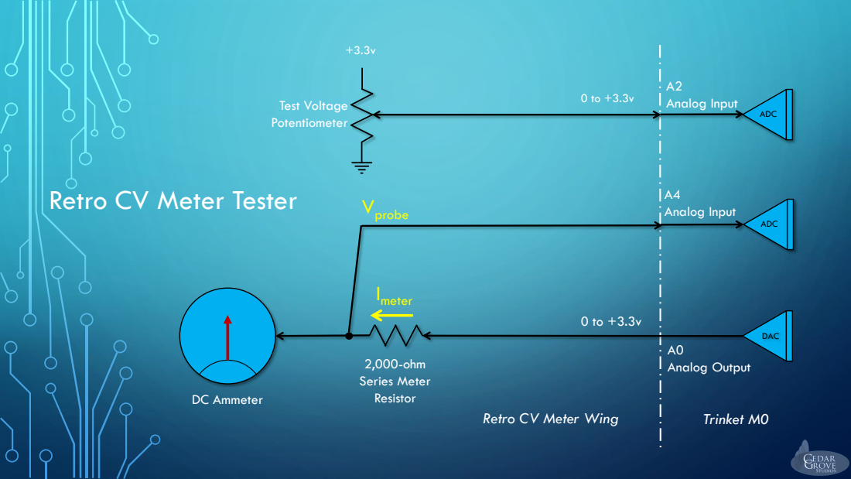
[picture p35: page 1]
A4 Analog Input; A0 Analog Output; Retro CV Meter Wing; Trinket M0; DAC; ADC; 2,000-ohm Series Meter Resistor; DC Ammeter; Test Voltage; Analog Input; Potentiometer; Imeter; Vprobe

Retro CV Meter Tester

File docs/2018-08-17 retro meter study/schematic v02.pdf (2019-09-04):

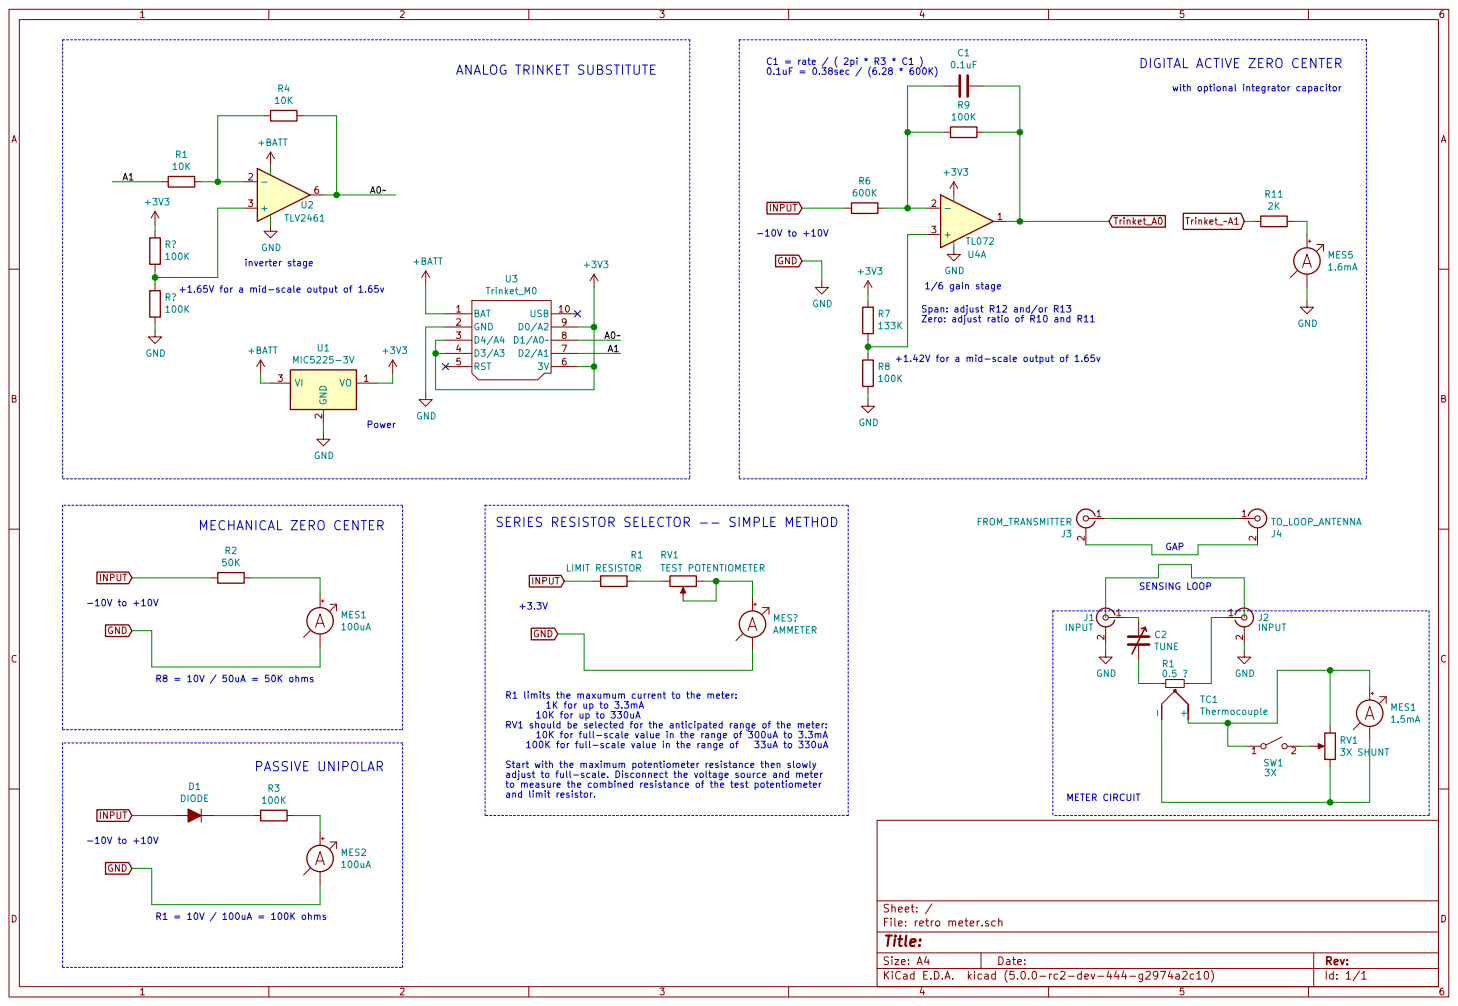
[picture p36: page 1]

Zero: adjust ratio of R10 and R11 C1

Span: adjust R12 and/or R13

+1.42V for a mid-scale output of 1.65v

+3.3V SERIES RESISTOR SELECTOR -- SIMPLE METHOD

-+ TC1 Thermocouple GAP GND GND

R1 limits the maxumum current to the meter:
1K for up to 3.3mA
10K for up to 330uA
RV1 should be selected for the anticipated range of the meter:
10K for full-scale value in the range of 300uA to 3.3mA
100K for full-scale value in the range of 33uA to 330uA
Start with the maximum potentiometer resistance then slowly
adjust to full-scale. Disconnect the voltage source and meter

MES2
Id: 1/1 Title: File: retro meter.sch Sheet: / A

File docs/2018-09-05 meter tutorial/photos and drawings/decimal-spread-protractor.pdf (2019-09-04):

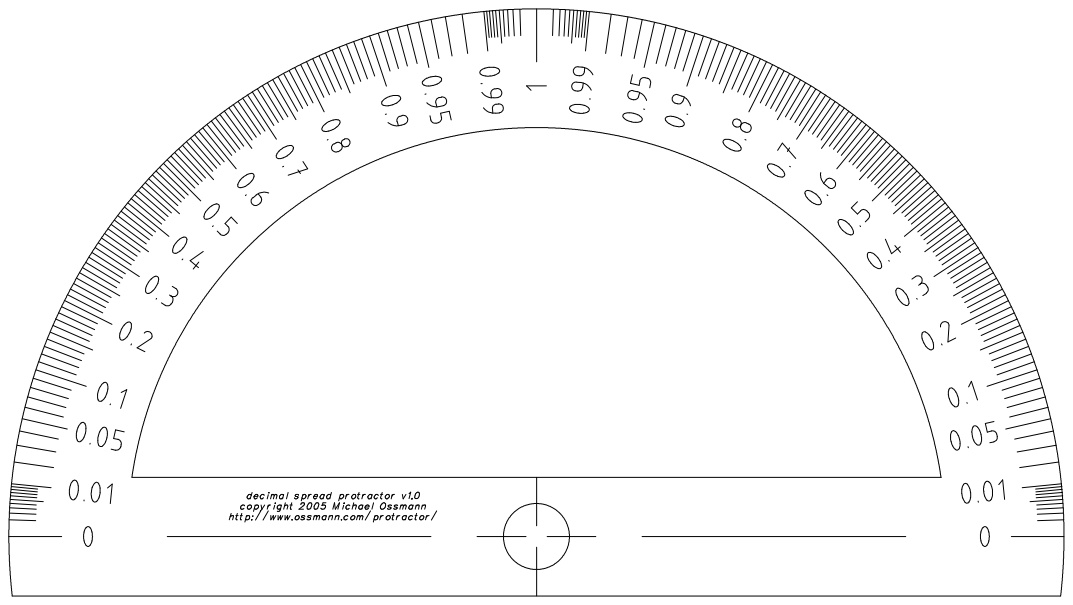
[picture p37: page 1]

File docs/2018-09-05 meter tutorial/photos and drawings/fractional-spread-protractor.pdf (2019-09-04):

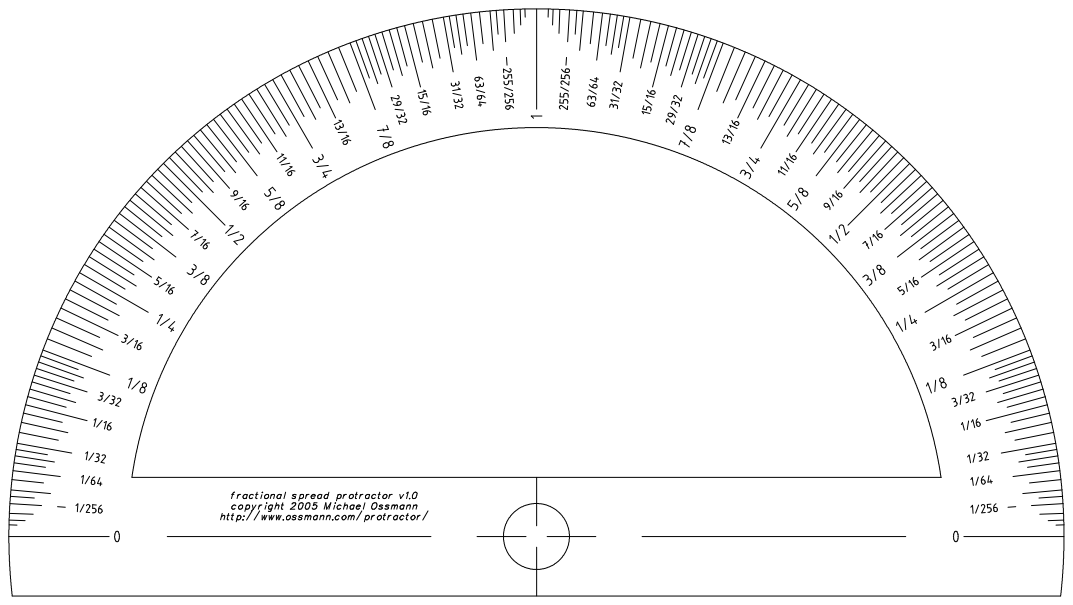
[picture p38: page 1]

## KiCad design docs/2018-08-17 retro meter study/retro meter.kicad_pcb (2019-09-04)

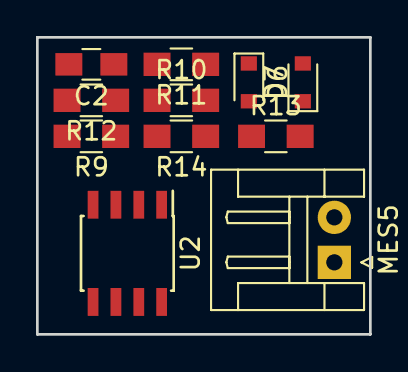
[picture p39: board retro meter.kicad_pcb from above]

Board: 2 copper layers, 18.5 x 16.5 mm, 11 parts (0 on the bottom side), 7 nets, no tracks yet.

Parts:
C2: 0.1uF; C_0805_HandSoldering
D6, D7: DIODE; D_0805
MES5: 100uA; JST_EH_S02B-EH_02x2.50mm_Angled
R9: 600K; R_0805_HandSoldering
R10, R11, R12: 100K; R_0805_HandSoldering
R13: 33K; R_0805_HandSoldering
R14: 10K; R_0805_HandSoldering
U2: TL072; SOIC-8_3.9x4.9mm_Pitch1.27mm

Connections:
+3V3: D6.1, R10.2
GND: D7.2, MES5.1, R11.1
unnamed: C2.1, R12.1, R14.2, U2.1
unnamed: C2.2, R9.1, R12.2, U2.2
unnamed: MES5.2, R13.1
unnamed: R10.1, R11.2, U2.3
Trinket_A0: D6.2, D7.1, R14.1

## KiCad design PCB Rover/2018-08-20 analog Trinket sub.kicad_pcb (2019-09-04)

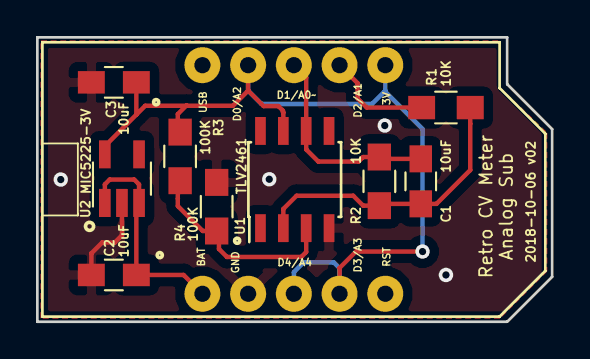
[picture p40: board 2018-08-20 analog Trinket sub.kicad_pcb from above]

Board: 2 copper layers, 28.6 x 15.8 mm, 10 parts (0 on the bottom side), 7 nets.

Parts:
C1, C2, C3: 10uF; C_0805_HandSoldering
R1, R2: 10K; R_0805_HandSoldering
R3, R4: 100K; R_0805_HandSoldering
U1: TLV2461; SOIC-8_3.9x4.9mm_Pitch1.27mm
U2: MIC5225-3V; SOT-23-5_HandSoldering
U3: Trinket_M0; Trinket_M0_no_holes

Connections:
+3V3: C3.1, R3.2, U1.7, U2.5, U3.3, U3.4, U3.6, U3.9
+BATT: C2.1, U2.1, U2.3, U3.1
/A0~~: C1.1, R2.1, U1.6, U3.8
/A1: R1.2, U3.7
GND: C2.2, C3.2, R4.1, U1.4, U2.2, U3.2
unnamed: C1.2, R1.1, R2.2, U1.2
unnamed: R3.1, R4.2, U1.3

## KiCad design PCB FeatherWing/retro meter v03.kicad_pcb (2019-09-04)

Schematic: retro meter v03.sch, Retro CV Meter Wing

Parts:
C1: 10uF; C_0805
C2: 0.1uF; C_0805
C3: 0.01uF; C_0805
D1: GRN LED; LED_0805_HandSoldering
J1: CV_INPUT; Pin_Header_Straight_1x02_Pitch2.54mm
J2: POWER_SWITCH; Pin_Header_Straight_1x02_Pitch2.54mm
J3: RANGE_SEL; Pin_Header_Straight_1x03_Pitch2.54mm
J4: METER_OUTPUT; Pin_Header_Straight_1x02_Pitch2.54mm
J5: LED1; Pin_Header_Straight_1x02_Pitch2.54mm
J6: LED2; Pin_Header_Straight_1x02_Pitch2.54mm
J7: LED3; Pin_Header_Straight_1x02_Pitch2.54mm
M1: Feather_M4_Express; Adafruit_Feather_M4_Express_bare
MES1: 1.6mA
P1: PKMCS0909E4000-R1
R1: 133K; R_0805
R2, R3, R5, R14, R15: 100K; R_0805
R4: 600K; R_0805
R6, R7: 10K; R_0805
R8: 2K; R_0805_HandSoldering
R9, R10, R11: 220; R_0805_HandSoldering
R12: 100M; R_Axial_DIN0309_L9.0mm_D3.2mm_P2.54mm_Vertical
R13: 470; R_0805
RV1: RANGE_SELECT
U1: TLV2462; SOIC-8_3.9x4.9mm_Pitch1.27mm
U2, U3, U4: 74HCT1G125; TSOP-5_1.65x3.05mm_Pitch0.95mm_hand_solder

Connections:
+3V3: C1.1, C2.1, J3.2, M1.2, R1.2, R13.2, R14.2, U1.8 (V+), U2.6, U3.6, U4.6
/-EN: J2.1, M1.18
/A0~~: M1.5, R8.2, R12.2
/A2: M1.7, R7.1, U1.7
/A3: J3.1, M1.8
/D5: M1.26, U2.2
/D6: M1.25, U3.2
/D9: M1.24, U4.2
/D10: M1.23, P1.1
/Vref1: R1.1, R2.2, U1.3 (+)
/Vref2: R14.1, R15.2, U1.5 (+)
GND: C1.2, C2.2, D1.1, J1.2, J2.2, J3.3, J4.2, J5.2, J6.2, J7.2, M1.4, P1.2, R2.1, R3.1, R15.1, U1.4 (V-), U2.1, U2.3, U3.1, U3.3, U4.1, U4.3
unnamed: C3.1, R5.1, R6.2, U1.1
unnamed: C3.2, R4.1, R5.2, U1.2 (-)
unnamed: D1.2, R13.1
unnamed: J1.1, R3.2, R4.2
unnamed: J4.1, R8.1, R12.1
unnamed: J5.1, R9.1
unnamed: J6.1, R10.1
unnamed: J7.1, R11.1
unnamed: R6.1, R7.2, U1.6 (-)
unnamed: R9.2, U2.4
unnamed: R10.2, U3.4
unnamed: R11.2, U4.4

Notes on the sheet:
Meter output scaling: Adjust R8 for meter full-scale value R8 = 3.3V / 1.5mA = 2.2K ohms
voltage sum stage CV gain = -0.1667 Vref gain = +1.1667
-10V to +10V
+1.416V
input -> output -10v 0v 0v +1.65v +10v +3.3v
power management
microcontroller
desired CV Gain = Voutpk_pk / Vinpk_pk desired CV Gain = 3.3v / 20v = 0.165 actual CV Gain = R5 / R4 = 0.1667 Vref1 = ( 3.3v / 2 ) / [ 1+ ( 100K / 600K ) ] Vref1 = 1.65v / 1.1667 Vref1 = 1.414v Actual Vref1 = [ 3.3v / ( 100K + 133K ) ] * 100K Actual Vref1 = 1.416v C1 = rate / ( 2pi * R5) 0.01uF = 0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
1.0 gain inverter stage
Standalone Analog Mode: Provide power to 3V pin using https://www.adafruit.com/product/2745 Jumper pin A0 to pin A2
(through-hole)
Vf=2.1v @ 5mA
Vf=2.1v @ 10mA
Feather Pin Usage: 3V: powers all internal components and external LEDs GND: common ground for everything A0~: digital-to-analog (DAC) output to series meter resistor A2: analog input from op-amp input signal processing stage A3: analog input from range selection potentiometer D5: digital output to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
range select input
piezo speaker
buffered LED outputs
analog input signal processing stage
+1.650V

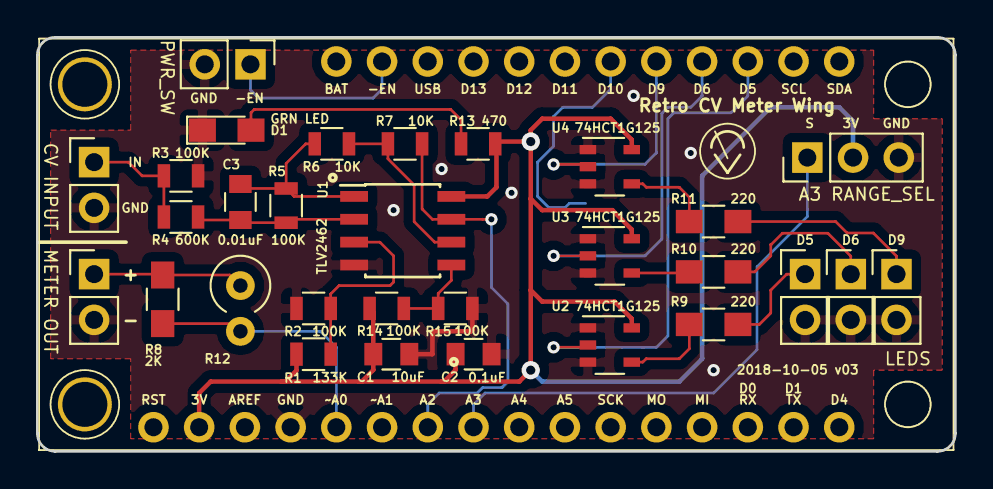
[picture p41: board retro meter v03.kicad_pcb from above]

Board: 2 copper layers, 51.0 x 23.0 mm, 32 parts (1 on the bottom side), 24 nets.

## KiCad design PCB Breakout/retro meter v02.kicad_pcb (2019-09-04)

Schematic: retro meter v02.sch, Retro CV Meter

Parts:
C1, C3: 0.1uF; C_0805_HandSoldering
C2: 10uF
J1: CV_INPUT; Pin_Header_Straight_1x02_Pitch2.54mm
J2: POWER_SWITCH; Pin_Header_Straight_1x02_Pitch2.54mm
J3: LIPO_BATTERY; JST_PH_S2B-PH-SM4-TB_02x2.00mm_Angled
J4: D0/A2; Pin_Header_Straight_1x03_Pitch2.54mm
J5: D3/A3; Pin_Header_Straight_1x03_Pitch2.54mm
J6: D4/A4; Pin_Header_Straight_1x03_Pitch2.54mm
J7: METER_OUTPUT; Pin_Header_Straight_1x02_Pitch2.54mm
MES1: 1.6mA
R2, R4, R6, R8: 100K; R_0805_HandSoldering
R3: 133K; R_0805_HandSoldering
R5: 600K; R_0805_HandSoldering
R9: 2K; R_0805_HandSoldering
U1: TLV2461; SOIC-8_3.9x4.9mm_Pitch1.27mm
U2: Trinket_M0; Trinket_M0_no_holes

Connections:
+3V3: C2.1, C3.1, J4.2, J5.2, J6.2, R3.2, R8.2, U1.7 (V+), U2.6
+BATT: J2.1, U2.1
/A0~~: R9.2, U2.8
/A1: C1.1, R6.1, U1.6, U2.7
/D0: J4.1, U2.9
/D3: J5.1, U2.4
/D4: J6.1, U2.3
/Vref: R3.1, R4.2, U1.3 (+)
GND: C2.2, C3.2, J1.2, J3.2, J4.3, J5.3, J6.3, J7.2, R2.1, R4.1, U1.4 (V-), U2.2
unnamed: C1.2, R5.1, R6.2, U1.2 (-)
unnamed: J1.1, R2.2, R5.2
unnamed: J2.2, J3.1
unnamed: J7.1, R9.1
unnamed: R8.1, U2.5

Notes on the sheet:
adjust R8 for meter full-scale value R8 = 3.3V / 1.6mA = 2K ohms
0.167 gain inverter stage
Span: adjust R6 Zero: adjust ratio of R3 and R4
C1 = rate / ( 2pi * R5) 0.1uF = 0.038sec / (6.28 * 60K)
-10V to +10V
+1.42V
input -> output -10v +3.3v 0v +1.65v +10v 0v
DAC output scaling
GPIO
power management
microcontroller
Vref = Rf ( Vinpk_pk / ( 2 ( Rf + Rin ) ) ) Vref = 10K ( 20v / ( 2 (10K + 60K ) ) ) Vref = 1.42v
Gain = Voutpk_pk / Vinpk_pk Gain = 3.3v / 20v = 0.165

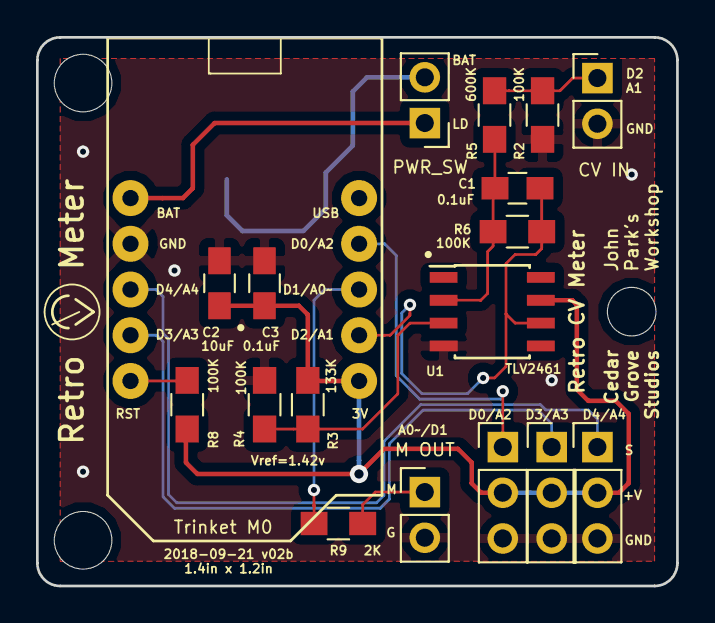
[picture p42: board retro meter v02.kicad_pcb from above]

Board: 2 copper layers, 35.6 x 30.5 mm, 19 parts (1 on the bottom side), 14 nets.

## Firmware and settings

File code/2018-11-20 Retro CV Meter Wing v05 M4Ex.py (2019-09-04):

# 2018-11-20 Retro CV Meter Wing v05 M4Ex.py
# Feather M4 Express-based CV monitor with analog current meter output
# (c) 2018 John Park's Workshop with Cedar Grove Studios
#
# The Retro CV Meter board accepts a -10 to +10 volt CV signal and outputs
#   a 0 to 1.5mA signal to a connected analog ammeter. The PCB attenuates and
#   shifts the incoming signal, translating it into a 0 to +3.3 volt signal
#   compatible with the Feather's A2 analog input pin.
#
# The Feather's A0~ DAC output pin provides a voltage that is converted to a
#   current through a 2K-ohm resistor to the analog ammeter. The maximum
#   16-bit DAC value (65535) produces 1.5mA to deflect the meter to full-scale.
#   The series resistor can be altered to adjust to various meters, as needed.
#
# This code reads the input voltage and adjusts the scale for the meter. The
#   inertia_move helper integrates and sends the scaled voltage to the series
#   meter resistor. Integration protects the meter movement from sudden voltage
#   changes.
#

import digitalio
import pulseio
from analogio import AnalogIn, AnalogOut
import board
import time
from simpleio import map_range
import neopixel as neo

import microcontroller  # for checking CPU temperature
import gc  # for checking memory capacity

# ### Setup ###
# CV input and meter output
cv_pin = AnalogIn(board.A2)
scale_pin = AnalogIn(board.A3)
meter_pin = AnalogOut(board.A0)

# Feather battery voltage monitor
battery_pin = AnalogIn(board.VOLTAGE_MONITOR)

# on-board activity indicator (when moving the meter needle)
led = digitalio.DigitalInOut(board.D13)
led.direction = digitalio.Direction.OUTPUT

# GPIO for pwm indicators
neg_led = pulseio.PWMOut(board.D5)  # negative red LED
pos_led = pulseio.PWMOut(board.D6)  # positive green LED
amber_led = pulseio.PWMOut(board.D9)  # absolute value amber LED

# piezo speaker (PWM output)
piezo = pulseio.PWMOut(board.D10, duty_cycle=0, frequency=440, variable_frequency=True)

# dim the on-board NeoPixel, white for startup
pixel = neo.NeoPixel(board.NEOPIXEL,1, brightness=0.01, auto_write=False)
pixel[0] = (200, 200, 200)
pixel.write()
time.sleep(0.1)

# ### Dictionaries and Lists ###

scales = [(-10, 10), (-8, 8), (-5, 5), (0, 5), (0, 8), (0, 10)]

# ### Helpers ###
def inertia_move(v=0, target_v=0, rate=1, increment=1, low_scale=-10, high_scale=10):
    # This helper moves the output voltage from the current value to the
    # target value at the specified rate (seconds per input volt). Output
    # resolution is controlled by increment and is measured in volts per step.
    # The output scale is controlled by the values of low_scale and high_scale.

    led.value = True  # turn on activity indicator

    # limit the voltage increment to a reasonable value
    if increment <= 0:
        increment = 0.001  # minimum increment of 1mV/step
    if increment > 5:
        increment = 5      # maximum increment of 5V/step

    # This is the proportional movement control. It determines the
    # number of steps needed to move from the current value to the target
    # value based on the increment value.
    #
    delta_v = target_v - v
    steps = delta_v / increment
    if steps == 0:  # have to take at least one step
        steps = 1

    # This portion of code steps from the current value to the target value
    # over time specified by the rate.
    #
    # This is where input voltage is scaled before sending to the DAC output.
    # The meter's full-scale voltage are controlled by the low_scale and
    # high_scale parameters
    #
    for i in range(1+int(abs(steps))):
        meter_pin.value = int(map_range(v, low_scale, high_scale, 0, 65535))
        time.sleep(rate * increment)
        v = v + ((steps / abs(steps)) * increment)
    v = target_v

    led.value = False  # clear activity indicator
    return (v)  # return new v value

def sign(x):  # determine the sign of x
    if x >= 0: s = 1
    else: s = -1
    return s

# ctl_idx (Control Index) converts an analog value to index integer
#  Input is masked to 8 bits to reduce noise then hysteresis offset
#  is applied. (ItsyBitsy M4 DAC and ADC are 12-bit; CircuitPython
#  converts to 16-bits.) The helper returns new index value, input
#  hysteresis offset based on max, and index change flag.
def ctl_idx(ctl, max, offset, old_idx):
    if (ctl + offset > 65535) or (ctl + offset < 0): offset = 0
    idx = int(map_range((ctl + offset) & 0xFF00,1200,65500, 0, max))
    if idx != old_idx:  # if index changed, adjust hysteresis offset and set flag
        # offset is 10% of the control slice (65536/max)
        offset = int(0.1 * sign(idx - old_idx) * (65535 / max))
        flag = True  # index value has changed
    else:
        flag = False  # index value is the same
    return idx, offset, flag

def beep_on(f=440):  # start PWM piezo beeper
    piezo.frequency = f
    piezo.duty_cycle = int(65535/2)  # tone on, 50%
    return True

def beep_off(w=0):  # stop PWM piezo beeper after wait
    if w != 0:
        time.sleep(w)
    piezo.duty_cycle = 0  # tone off
    return True

def click():  # play click sound/beep
    beep_on(440)  # A4
    beep_off(0.025)
    return True

def hello_A():  # play hello tune in key of A major
    beep_on(880)  # A5
    beep_off(0.25)
    beep_on(1109)  # C#6
    beep_off(0.25)
    beep_on(1319)  # E6
    beep_off(0.25)
    time.sleep(0.25)
    return True

# ### Set Initial Parameters ###
#
# The following parameters set rate, increment, and outut hold. You should
#   experiment with these parameters to get the right "feel" for the particular
#   application and analog meter.
#
move_rate = 0.050    # seconds to move 1 volt on a -10 to +10 volt scale
move_inc = 0.050     # smallest movement representing input voltage
output_hold = 0  # number of seconds to hold position before repositioning

# Initialize the hysteresis and scale values
scale_max = 6
scale_idx = 0
scale_offset = 0
meter_low, meter_high = scales[0]  # set default meter output scale values

print("2018-11-20 Retro CV Meter Wing v05 M4Ex.py")
print("GC.mem_free:  %0.3f" % float(gc.mem_free()/1000), "KB")
print("CPU.freqency:   %0.1f" % float(microcontroller.cpu.frequency/1000000), "MHz")
print("CPU.temperature: %0.1f" % microcontroller.cpu.temperature, "C")
print("Battery voltage:  %0.1f" % map_range(battery_pin.value, 0, 65535, 0, 6.6), "V")
print("Movement rate: %0.3f" % move_rate, "seconds/volt; Output hold: %0.3f" % output_hold, "seconds")
print("Minimum movement increment: %0.3f" % move_inc, "volts")
print("Initial meter scale: %1.0f" % meter_low, "to %1.0f" % meter_high, "volts")

hello_A()

# Slowly center (zero) the meter's output before reading the input voltage.
#   This should take about one second to move the needle to the center.
meter_out_volt = inertia_move(-10, 0, 0.200, 0.050)
time.sleep(0.500)  # hold at center scale for 0.500 seconds

t0 = time.monotonic()  # set a timer for the scale potentiometer input rate

# ### Main Loop ###
while True:
    if time.monotonic() > t0 + 0.500:  #read the scale potentiometer every 500msec
        scale_idx_old = scale_idx  # remember the index for the previous range
        (scale_idx, scale_offset, scale_flag) = ctl_idx(scale_pin.value, scale_max, scale_offset, scale_idx_old) # determine scale index
        if scale_flag:  # if the index changed, blink the amber led
            amber_led.duty_cycle = 0
            click()
            amber_led.duty_cycle = 65535
            meter_low, meter_high = scales[scale_idx]  # set the meter scale limits
            print("Scale: %1.0f" % meter_low, "to %1.0f" % meter_high, "volts")
        t0 = time.monotonic()  # reset the scale potentiometer input timer

    # Read the CV input and map to a +/-10V value.
    #   A 3.3V input maps to a value of +10V. DO NOT adjust these values.
    cv_input_volt = map_range(cv_pin.value, 0, 65535, -10, +10)

    # Show the input voltage value and polarity on the DotStar indicator and leds
    if cv_input_volt > +1.0:    # 1V noise threshold
        pixel[0] = (0, 255, 0)  # green = positive
        pixel.write()
        # pos_led.duty_cycle = int(map_range(cv_input_volt, 1, meter_high, 0, 65535))
        amber_led.duty_cycle = int(map_range(cv_input_volt, 1, meter_high, 4096, 65535))
    elif cv_input_volt < -1.0:  # 1V noise threshold
        pixel[0] = (255, 0, 0)  # red = negative
        pixel.write()
        # neg_led.duty_cycle = int(map_range(cv_input_volt, -1, meter_low, 0, 65535))
        amber_led.duty_cycle = int(map_range(cv_input_volt, -1, meter_low, 4096, 65535))
    else:
        pixel[0] = (0, 0, 255)  # blue = zero
        pixel.write()
        # pos_led.duty_cycle = 0
        # neg_led.duty_cycle = 0
        amber_led.duty_cycle = 4096

    # Send the scaled input voltage to the analog meter via the inertia_move
    #   helper to the Trinket DAC output.
    meter_out_volt = inertia_move(meter_out_volt, cv_input_volt, move_rate, move_inc, meter_low, meter_high)

    time.sleep(output_hold)  # Hold the output voltage for a while.

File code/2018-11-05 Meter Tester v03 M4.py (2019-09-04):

# 2018-11-05 Meter Tester v03 M4.py
# Feather M4-based analog meter tester utilizing the Retro CV Meter Wing
# (c) 2018 John Park's Workshop with Cedar Grove Studios
#
# The Meter Tester measures and displays analog meter parameters. The
#   meter voltage is monitored by a probe connection from analog input A4.
#   Up to +1.65mA current is output from the Retro CV Meter Wing to the
#   meter under test. The test potentiometer (attached to analog
#   input A3) is manually adjusted from zero to a level that causes the
#   meter to deflect to full-scale. The OLED continuously displays
#   meter parameters and recommended DAC resistor value.
#
# The Feather's A0~ DAC output pin provides a voltage that
#   is converted to a current through a series resistor to the analog ammeter.
#   The maximum 12-bit DAC value (65520 in the 16-bit CPy range of values)
#   produces 1.65mA to deflect the meter to full-scale when the series resistor
#   value is 2000 ohms, the recommended minimum series resistor value.
#

import digitalio
import pulseio  # for LED brightness control
import busio  # for the OLED wing
from analogio import AnalogIn, AnalogOut
import board
import time
from simpleio import map_range
import adafruit_ssd1306  # OLED wing
import neopixel as neo # on-board NeoPixel
import microcontroller  # for checking CPU temperature
import gc  # for checking memory capacity

# ### Setup ###
i2c = busio.I2C(board.SCL, board.SDA)
oled = adafruit_ssd1306.SSD1306_I2C(128, 32, i2c)
oled.fill(0)
oled.show()

# analog inputs and meter output
probe_pin = AnalogIn(board.A4)
test_pin = AnalogIn(board.A3)
meter_pin = AnalogOut(board.A0)
meter_pin.value = 0  # Position the meter to zero

# on-board activity
led = digitalio.DigitalInOut(board.D13)
led.direction = digitalio.Direction.OUTPUT
led.value = True

# GPIO for pwm indicators
# neg_led = pulseio.PWMOut(board.D5)  # negative red LED
# pos_led = pulseio.PWMOut(board.D6)  # positive green LED
amber_led = pulseio.PWMOut(board.D9)  # absolute value amber LED
amber_led.duty_cycle = 32000  # turn on amber LED for general illumination

# piezo speaker (PWM output)
piezo = pulseio.PWMOut(board.D10, duty_cycle=0, frequency=440, variable_frequency=True)

# dim the on-board NeoPixel, white for startup
pixel = neo.NeoPixel(board.NEOPIXEL,1, brightness=0.01, auto_write=False)
pixel[0] = (200, 200, 200)
pixel.write()
time.sleep(0.1)

# ### Dictionaries and Lists ###
scales = [(-10, 10), (-8, 8), (-5, 5), (0, 5), (0, 8), (0, 10)]  # for music

# ### Helpers ###
def beep_on(f=440):  # start PWM piezo beeper
    piezo.frequency = f
    piezo.duty_cycle = int(65535/2)  # tone on, 50%
    return True

def beep_off(w=0):  # stop PWM piezo beeper after wait
    if w != 0:
        time.sleep(w)
    piezo.duty_cycle = 0  # tone off
    return True
    
def hello_A():  # play hello tune in key of A major
    beep_on(880)  # A5
    beep_off(0.25)
    beep_on(1109)  # C#6
    beep_off(0.25)
    beep_on(1319)  # E6
    beep_off(0.25)
    time.sleep(0.25)
    return True

# ### Set Initial Parameters ###
output_hold = 2  # number of seconds to hold measurement display
dac_resist = 39.89e3 # the PCB's series meter resistor value in ohms
test_volt = 0
probe_volt = 0

print("2018-11-05 Meter Tester v03 M4.py")
hello_A()

# splash screen
oled.text("Meter Tester v03", 0, 0)
oled.text("  Free:", 0, 8)
oled.text(str(int(gc.mem_free()/1e2)/10), 64, 8)
oled.text("  Freq: ", 0, 16)
oled.text(str(int(microcontroller.cpu.frequency/1e5)/10), 64, 16)
oled.text("  Temp:", 0, 24)
oled.text(str(int(microcontroller.cpu.temperature*10)/10), 64, 24)
oled.show()
time.sleep(3)

# information screen
oled.fill(0)
oled.text("Meter Tester v03", 0, 0)
oled.text("  Adjust from", 0, 8)
oled.text("  zero setting", 0, 16)
oled.text("  to full-scale", 0, 24)
oled.show()
time.sleep(3)

pixel[0] = (0, 0, 200)  # blue when operating
pixel.write()
led.value = False  # turn off the activity LED

# start the display timer
t0 = time.monotonic()

# ### Main Loop ###
while True:
    meter_pin.value = test_pin.value  # set the meter output voltage to the test voltage value

    if time.monotonic() > t0 + output_hold:  # change the display based on output_hold value
        # read the test voltage from the potentiometer and meter probe inputs
        #   scale from pseudo 12-bit value to actual voltage, accurate to three places
        test_volt = int(((test_volt + map_range(test_pin.value, 0, 65520, 0, 3.3)) / 2)*1e3)/1e3
        probe_volt = int(((probe_volt + map_range(probe_pin.value, 0, 65520, 0, 3.3)) / 2)*1e3)/1e3

        if probe_volt > test_volt: probe_volt = test_volt  # prevent negative values
        
        # calculate meter current and voltage values
        meter_current = (test_volt - probe_volt) / dac_resist
        meter_volt = probe_volt

        # calculate meter and DAC resistances
        if (test_volt - probe_volt) != 0:
            meter_resist = (probe_volt * dac_resist) / (test_volt - probe_volt)
            new_dac_resist = (3.3 - meter_volt) / meter_current
        else:
            meter_resist = None
            new_dac_resist = None
            
        oled.fill(0)
        oled.show()
        led.value = True  # turn on the activity LED
        
        if test_volt <= 0.05:  # don't start until the test voltage is > 50mV
            oled.text("LOW TEST VOLTAGE", 0, 0)
        else:
            oled.text("M mA=", 0, 0)  # meter milliamps, accurate 3 places
            oled.text(str(int(meter_current * 1e6)/1e3), 64, 0)
            oled.text("M mV=", 0, 8)  # meter millivolts, accurate 3 places
            oled.text(str(int(meter_volt * 1e4)/10), 64, 8)
            if meter_resist != None:
                oled.text("M ohms=", 0, 16)  # meter resistance
                oled.text(str(meter_resist), 64, 16)
                oled.text("DAC R =", 0, 24)  # recommended DAC resistor at +3.3V
                oled.text(str(int(new_dac_resist)), 64, 24)
            else:
                oled.text(" ---  Check  ---", 0, 16)
                oled.text("   Connections", 0, 24)

        oled.show()
        t0 = time.monotonic()

    time.sleep(output_hold/10)  # hold the test voltage for a while
    led.value = False  # turn off the activity LED

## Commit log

2018-08-21 jst connector
    added battery jst connector
    [RetroMeter BOM.xlsx]
2018-09-01 Added external LED support
    Polarity indicators added to GPIO pins. D0=1 when signal is negative, D2=1 when signal is near zero, D4=1 when signal is positive.
2018-09-10 selectable scales version
    Reads the 0 to 3.3volt value on pin A2 to select and apply one of six ranges: +/-10v, +/-8v, +/-5v, 0/5v, 0/8v, 0/10v
2018-09-10 meter scale selection via analog input A2
    updated to include scale selection via analog input A2
    moved negative signal level LED from D0 to D3
2018-09-17 amber led version
    amber led attached to D3
2018-09-21 added feather wing files
2018-09-30 updated meter scale control
    Added hysteresis to the scale control potentiometer input. Changes to the scale flash the amber LED on D3.
2018-10-02 analog meter tester utilizing the Retro CV Meter PCB
    The Meter Tester measures and displays analog meter parameters. The meter voltage is monitored by a probe connection from analog input A4. Up to +1.65mA current is output from the Retro CV Meter boar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
2018-10-03 analog meter tester utilizing Retro CV Meter PCB
    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
2018-10-14 updated for revised PCB
    [RetroMeter BOM v02.xlsx]
2019-09-04 include alternate board designs
    [2018-08-20 analog Trinket sub-B.Cu.gbr, 2018-08-20 analog Trinket sub-B.Mask.gbr, 2018-08-20 analog Trinket sub-B.Paste.gbr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]
2021-07-12 update documentation
    [RetroMeter BOM v02.xlsx, RetroMeterWing v03 BOM jp 2018-10-31.xlsx, RetroMeterWing v03 BOM.xlsx]
